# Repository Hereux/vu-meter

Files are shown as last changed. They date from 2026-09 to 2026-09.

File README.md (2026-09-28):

# Bass-SPL-Meter (10-100 Hz)

Selbstbau-Messgerät für Schalldruckpegel im Subbassbereich — für Showcars und
Car-Audio-Anlagen. Zeigt kalibrierten Pegel in dB SPL und die dominante
Frequenz an, vergleichbar mit kommerziellen Geräten wie dem Basshead Garage
BHG-DB.

## Eckdaten

| | |
|---|---|
| Messbereich | ca. 95 … 178 dB SPL |
| Frequenzbereich | 10 … 100 Hz, im Menü auf 5 … 150 Hz umschaltbar |
| Frequenzauflösung | 0,6-1,2 Hz (FFT), f0 auf < 0,01 Hz interpoliert |
| Anzeige | 2,8" TFT: Pegel, Peak-Hold, dominante Frequenz, Spektrum |
| Messwandler | Absolut-Drucksensor BMP581 (kein Mikrofon) |
| Rechner | ESP32 |
| Versorgung | 9-18 V Bordnetz |
| Materialkosten | 55 EUR (AliExpress) bis 95 EUR (deutsche Shops) |

## Grundidee

Ein Mikrofon scheidet aus: bezahlbare Kapseln clippen ab ~130 dB und sind unter
20 Hz taub. Ein barometrischer Absolut-Drucksensor misst dagegen bis ~178 dB,
reicht bis 0 Hz hinunter und liefert den Messwert **direkt in Pascal** — die
Kalibrierung ist damit ab Werk gegeben, statt von einer unbekannten
Mikrofonempfindlichkeit abzuhängen.

## Dokumentation

| Datei | Inhalt |
|---|---|
| [docs/01-messprinzip.md](docs/01-messprinzip.md) | Warum Drucksensor statt Mikrofon, Physik, Sensorauswahl, Aliasing |
| [docs/02-hardware.md](docs/02-hardware.md) | Stückliste mit Preisen, Blockschaltbild, Pinbelegung, Bordnetzschutz |
| [docs/03-firmware.md](docs/03-firmware.md) | Signalkette, FFT-Parameter, Betriebsmodi, Codestruktur |
| [docs/04-gehaeuse.md](docs/04-gehaeuse.md) | 3D-Druck, Material, Druckport, Entkopplung, Montage |
| [docs/05-kalibrierung.md](docs/05-kalibrierung.md) | Gain-Prüfung per Wassersäule, Frequenzgang, Grenzen des Geräts |
| [docs/06-phase1-ergebnisse.md](docs/06-phase1-ergebnisse.md) | Messergebnisse des DSP-Modells und die Befunde daraus |
| [docs/07-warum-cpp.md](docs/07-warum-cpp.md) | Warum die Gerätesoftware C++ ist und Python die Referenz bleibt |
| [docs/08-einkaufsliste.md](docs/08-einkaufsliste.md) | Bezugsquellen, Artikelnummern, zwei Bestellwege |
| [firmware/README.md](firmware/README.md) | Aufbau der Firmware, Testen ohne Hardware |
| [case/README.md](case/README.md) | Gehäusemodell, Messliste, Druckeinstellungen |
| **[TASKS.md](TASKS.md)** | **Abarbeitungsliste in 9 Phasen mit Abnahmekriterien** |

## Werkzeuge

```bash
python3 tools/spl_calc.py          # Auslegung: Pegel/Druck, Sensorreserve, FFT-Parameter
python3 tools/dsp_model.py         # Referenzmodell der Messkette, Kennwerttabellen
python3 tools/test_dsp_model.py    # 99 Abnahmetests, Exitcode 0 = bestanden
python3 tools/export_reference.py  # Sollwerte fuer die C++-Portierung erzeugen
```

Alles reine Standardbibliothek — kein numpy, kein scipy, keine Installation.

```bash
make -C firmware test   # 142 Abnahmetests der C++-Portierung, nur g++ noetig
make -C firmware bench  # Durchsatzmessung
```

## Status

**Phase 1 abgeschlossen, Phase 3 vorgezogen, soweit ohne Hardware möglich.**

- DSP-Referenzmodell in Python: Pegelfehler ±0,03 dB, Frequenzfehler ±0,01 Hz
  über das gesamte Messband, 99 Tests → [docs/06-phase1-ergebnisse.md](docs/06-phase1-ergebnisse.md)
- C++-Portierung für den ESP32: 151 Tests gegen die Referenzwerte des Modells,
  läuft ohne Board → [firmware/README.md](firmware/README.md)
- Parametrisches Gehäusemodell mit Passungslehre und 1:1-Papiervorlage
  → [case/README.md](case/README.md)

Als Nächstes: **Phase 0 (Bestellung)** — sie blockiert alles Weitere. Danach
Phase 2 (Sensor-Bringup) aus [TASKS.md](TASKS.md).

## Hinweis

Kein geeichtes Messgerät. Keine Zertifizierung nach IEC 61672, nicht für
offizielle Wettbewerbsergebnisse geeignet. Details in
[docs/05-kalibrierung.md](docs/05-kalibrierung.md), Abschnitt E.

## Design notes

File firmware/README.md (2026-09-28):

# Firmware

Die Messkette ist in zwei Schichten geteilt:

| Schicht | Dateien | Hardware nötig? | Status |
|---|---|---|---|
| DSP-Kern | `src/dsp.*`, `src/spectrum.*`, `src/meter.*` | nein | **fertig, 142 Tests grün** |
| Zielsystem | `src/main.cpp` | ja | läuft, auch ohne Sensor — siehe Demobetrieb |

Der DSP-Kern ist frei von Arduino- und ESP-IDF-Abhängigkeiten. Genau deshalb
läuft derselbe Code im PC-Test, der ihn gegen die Referenzwerte aus dem
Python-Modell prüft.

## Testen ohne Hardware

```bash
make -C firmware test     # 142 Abnahmetests gegen tools/dsp_model.py
make -C firmware bench    # Durchsatzmessung
```

Nur `g++` nötig. Mit PlatformIO alternativ `pio test -e native`.

## Aufs Board bringen

```bash
pio run -e esp32 -t upload --upload-port COM13   # Windows
pio run -e esp32 -t upload --upload-port /dev/ttyUSB0
pio device monitor -b 115200 -p COM13            # Ausgabe mitlesen
```

Wer keine Toolchain einrichten will: der CI-Lauf legt die Binärdateien als
Artefakt `firmware-esp32` ab (Actions-Tab → Lauf öffnen → Artifacts). Flashen
dann mit `esptool`:

```
esptool.py --port COM13 --chip esp32 write_flash \
  0x1000 bootloader.bin 0x8000 partitions.bin 0x10000 firmware.bin
```

Vorher die TFT-Flags in `platformio.ini` und die Pinbelegung in
`include/config.h` gegen die eigene Boardrevision prüfen — von den CYD-Boards
gibt es mehrere Varianten.

### Hintergrundbeleuchtung

GPIO 21, aktiv HIGH, per PWM geregelt (`cfg::kBacklightDefault`, Vorgabe 80 %).
Der aktuelle Wert steht in der Statuszeile.

**GPIO 21 darf nicht für I²C verwendet werden**, obwohl 21/22 die
Arduino-Standardpins sind: `Wire.begin()` konfiguriert den Pin um und schaltet
die Beleuchtung aus. Das Display zeigt dann ein korrektes, aber dunkles Bild.
Zwei `static_assert` in `include/config.h` verhindern das jetzt zur
Übersetzungszeit — I²C liegt auf 27/22.

## Demobetrieb ohne Sensor

Findet die Firmware beim Start keinen BMP581, schaltet sie automatisch in den
Demobetrieb: ein synthetischer Sinus-Sweep von 20 auf 80 Hz bei 150 dB läuft
durch **dieselbe Messkette** wie später der echte Schall.

Damit lässt sich schon vor dem Sensor prüfen:

- Display, Rotation und Farben stimmen
- die Rechenkette läuft auf echter Hardware in Echtzeit
- die Anzeige zeigt plausible Werte: **150,0 dB** konstant, die Frequenz
  wandert in 12 s von 20 auf 80 Hz und springt dann zurück

Weicht der angezeigte Pegel von 150 dB ab oder hakt die Frequenz, stimmt etwas
in der Kette oder am Timing nicht — das ist der eigentliche Zweck.

Die Sensorerkennung liest nur die Chip-ID (0x50) auf 0x47 bzw. 0x46. Dafür
braucht es keine Herstellerbibliothek; der richtige Treiber kommt in Phase 2.

Bleibt das Display dunkel: die serielle Ausgabe alle 5 s zeigt dieselben Werte.
Kommt dort etwas an, läuft die Firmware und nur die Display-Konfiguration
stimmt nicht.

## Referenzwerte neu erzeugen

Nach jeder Änderung am Python-Modell:

```bash
python3 tools/test_dsp_model.py     # erst das Modell absichern
python3 tools/export_reference.py   # dann die Sollwerte neu schreiben
make -C firmware test               # dann die Portierung dagegen prüfen
```

Diese Reihenfolge ist wichtig: die Referenzwerte sind nur so gut wie das
Modell, aus dem sie stammen.

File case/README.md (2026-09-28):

# Gehäuse und Druckteile

Parametrisches OpenSCAD-Modell. Alle Maße stehen in `params.scad` — das ist
die einzige Datei, die du anfassen musst.

## ⚠️ Zuerst lesen: die Maße sind nicht verifiziert

Die mit `MESSEN` markierten Werte in `params.scad` sind **plausible
Startwerte, keine gemessenen**. Die im Netz auffindbaren Angaben zum
ESP32-2432S028R widersprechen sich (78 × 42 mm gegen 102 × 68 mm), und die dort
genannte Displayfläche passt rechnerisch nicht zu 2,8" Diagonale: bei 320 × 240
im Format 4:3 ergeben sich 56,9 × 42,7 mm aktive Fläche.

Ich konnte das nicht auflösen — die Shop- und Datenblattseiten sind aus meiner
Arbeitsumgebung nicht erreichbar. Also: **nachmessen, bevor du druckst.**

## Ablauf, der Fehldrucke vermeidet

```
1.  Papiervorlage      make drawing    ->  img/template.svg
    Ausdrucken bei 100 % (Skalierung im Druckdialog AUS), Platine drauflegen.
    Kostet ein Blatt Papier.

2.  Maße eintragen     params.scad
    Messschieber an die Platine, Werte ersetzen.

3.  Passungslehre      make fit        ->  stl/fit_test.stl
    ca. 15 min Druckzeit. Prüft Spiel, Gewindeeinsatz, USB-Ausschnitt,
    Wandstärke und Auflagehöhe -- an echter Geometrie, nicht an einer Kopie:
    fit_test.scad schneidet ein 25 mm langes Stück aus der echten Rückschale.

4.  Erst dann          make            ->  alle STLs
    Das Gehäuse braucht etwa 6 Stunden. Die 15 Minuten vorher sind gut angelegt.
```

## Messliste

Mit dem Messschieber an die Platine, Werte in `params.scad` eintragen:

| Parameter | Was messen |
|---|---|
| `pcb_l`, `pcb_w`, `pcb_t` | Platinenumriss und -dicke |
| `pcb_top_h` | höchstes Bauteil **über** der Platine (meist der Displayrahmen) |
| `pcb_bot_h` | höchstes Bauteil **unter** der Platine |
| `win_l`, `win_w` | sichtbare Displayfläche, plus ~1 mm Reserve |
| `win_off_l`, `win_off_w` | Versatz des Displays gegenüber der Platinenmitte |
| `usb_w`, `usb_h`, `usb_off` | USB-Buchse: Breite, Höhe, Versatz aus der Mitte |
| `sd_w`, `sd_h`, `sd_off` | microSD-Schlitz |
| `insert_d`, `insert_h` | die tatsächlich gelieferten Gewindeeinsätze |
| `sensor_pcb_l/w` | Breakout-Platine des BMP581 |

## Teile

| Datei | Was | Druckzeit |
|---|---|---|
| `stl/fit_test.stl` | Passungslehre — **das zuerst** | ~15 min |
| `stl/back.stl` | Rückschale mit Sensorkammer | ~4 h |
| `stl/bezel.stl` | Frontblende | ~2 h |
| `stl/cal_cup.stl` + `cal_lid.stl` | Kalibrierkammer, siehe unten | ~1,5 h |

## Die zwei Kammern nicht verwechseln

**Sensorkammer am Gerät** (`case.scad`, `sensor_pod`): auf allen vier Seiten
**offen**. Genau so soll es sein — ein dichtes Volumen wirkt als Hochpass und
dämpft die tiefen Frequenzen weg, um die es hier geht. Über die Öffnungen kommt
offenporiger Schaumstoff gegen Staub und direkten Luftzug; der ist bei diesen
Frequenzen akustisch transparent.

**Kalibrierkammer** (`sensor_chamber.scad`): **dicht**. Nur in einem
geschlossenen Volumen lässt sich dem Sensor ein bekannter Überdruck vorsetzen.
Details in [../docs/05-kalibrierung.md](../docs/05-kalibrierung.md).

Ein Schraubglas tut es übrigens auch — die gedruckte Kammer hat nur schon die
Schlauchtülle dran.

## Druckeinstellungen

| | |
|---|---|
| Material | **ASA oder PETG. Kein PLA** — im Fahrzeug bis 80 °C, PLA verformt sich ab 55 °C |
| Schichthöhe | 0,2 mm |
| Perimeter | 4 — das Gehäuse muss steif sein, sonst schwingt es bei 150 dB selbst mit |
| Infill | 25 % |
| Stützen | keine, außer an der Schlauchtülle der Kalibrierkammer |
| Orientierung | Rückschale mit dem Boden aufs Bett, Sensorkammer nach oben |

Gewindeeinsätze mit dem Lötkolben bei ~230 °C einschmelzen, senkrecht und ohne
Druck. Direkt gedruckte Gewinde reißen bei Vibration aus.

## Nach dem Zusammenbau

Die Sensorplatine auf 2 mm Moosgummi setzen und nur leicht andrücken. Bei
150 dB wird das Gehäuse selbst zur schwingenden Masse; ein starr verschraubter
Sensor misst diese Beschleunigung als Scheindruck mit.

**Frequenzgang nach dem Einbau erneut messen** (Phase 6.5). Das Gehäuse ist der
wahrscheinlichste Fehlerort im ganzen Projekt.

## Eine Notiz zum Modell selbst

Beim Erstellen sind sechs Fehler aufgefallen, alle erst beim Ansehen der
gerenderten Bilder, nicht beim Kompilieren:

- Der Innenraum war nur um die Platine herum ausgehöhlt — die Stirnseiten
  blieben massiv stehen, der USB-Ausschnitt wäre ein 8 mm tiefer Tunnel
  gewesen, in den kein Stecker passt.
- Ein `rotate()` vertauschte Breite und Wanddurchbruch des microSD-Schlitzes.
- Lüftungsschlitze schnitten in den microSD-Ausschnitt.
- Die Sensorkammer dünnte den Wannenboden auf 1,2 mm aus.
- Die Zugentlastungspfosten standen auf massivem Material außerhalb des
  Innenraums und waren damit wirkungslos.
- Ein Zugentlastungspfosten lag exakt tangential an einer Auflageleiste. Eine
  Berührung ohne Durchdringung — daran scheitert CGAL, und das STL wurde
  nicht-mannigfaltig.

Dass so etwas beim reinen Kompilieren durchgeht, ist der Grund für die
Papiervorlage und die Passungslehre.

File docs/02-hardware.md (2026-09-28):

# 2. Hardware und Stückliste

## Architektur

```
 12 V Bordnetz
   |  Sicherung 1 A + Verpolschutz + TVS (SMBJ24A)
   v
 DC/DC 12 V -> 5 V (MP1584 / LM2596)
   |
   v
 ESP32-2432S028R  ("Cheap Yellow Display")
   +-- 2.8" TFT 320x240 ILI9341 (SPI, onboard)
   +-- microSD (SPI, onboard)  -> Logging
   +-- I2C (GPIO 27 SDA / 22 SCL)              --> BMP581
   +-- Taster (GPIO 35 o. Touch)               --> Mode / Peak-Reset
   +-- WLAN (optional)                          --> Web-UI / OTA
```

## Stückliste

| # | Teil | Zweck | Preis (EUR) | Quelle |
|---|---|---|---|---|
| 1 | ESP32-2432S028R, 2.8" TFT + microSD + Touch | MCU + Display + Logging in einem | 12-16 | AliExpress, Amazon |
| 2 | BMP581 **Breakout-Platine** (SparkFun Qwiic / DFRobot / generisch) | Messwandler | 12-29 | AliExpress ~12-15, Eckstein/BerryBase ~27-29. **Kein nackter LGA-10-Chip** |
| 3 | DC/DC 12 V -> 5 V, **fester** Ausgang, Eingang bis >= 40 V | Bordnetzversorgung | 3-7 | AliExpress ~3, oder RECOM R-78B50-10 (Reichelt Art. 159150) ~7 |
| 4 | TVS SMBJ24A, Schottky SS34, Sicherungshalter + 1 A Flachsicherung | Load-Dump-/Verpolschutz | 3-5 | Reichelt |
| 5 | Elkos 470 µF/35 V + 100 µF/10 V, Ferritperle | Siebung, Störunterdrückung | 2 | Reichelt |
| 6 | Kabel 2×0,75 mm², JST-XH-Steckverbinder, Schrumpfschlauch | Verkabelung | 4 | — |
| 7 | Filament ASA oder PETG, ~80 g | Gehäuse (hitzefest im Auto) | 2-3 | — |
| 8 | Gewindeeinsätze M3 (8×), Schrauben M3×8 | Gehäuseverschraubung | 3 | — |
| 9 | Saugnapfhalterung 30 mm (2×) oder GoPro-Mount | Befestigung Scheibe/Armaturenbrett | 4-7 | — |
| 10 | Taster 12 mm wasserdicht (optional, sonst Touch) | Peak-Reset | 2 | — |
| | **Summe** | | **55-95** | |

Optional im Budgetrahmen:

| Teil | Zweck | Preis |
|---|---|---|
| Zweiter Sensor BMP390 | Plausibilitätsprüfung / Redundanz | 8-12 |
| Kalibrier-Set: Schlauch 6 mm, 60 ml Spritze, Lineal | statische Gain-Prüfung (siehe Doc 05) | 5 |
| Bluetooth-/WLAN-Logging (nur Software) | Auswertung am Handy | 0 |

**Gesamt realistisch 55 EUR (AliExpress-Weg) bis 95 EUR (deutscher Weg)**
inkl. Kalibrierhilfsmittel — beides im Budgetrahmen.

Konkrete Bezugsquellen mit Artikelnummern: [08-einkaufsliste.md](08-einkaufsliste.md).

## Warum das ESP32-2432S028R-Board

Es ist die mit Abstand kosteneffektivste Option: ESP32-WROOM-32, 2,8" TFT,
Touch, microSD, USB-Seriell, Spannungsregler und LDR schon verbaut, für den
Preis eines nackten DevKits. Die klassische ESP32 leistet eine 512-Punkt-FFT bei
600 Hz Abtastrate mit <2 % CPU-Last — mehr als ausreichend.

Falls ein größerer Rechenpuffer oder besseres Sonnenlichtverhalten gewünscht
ist:
- **ESP32-S3 DevKitC-1 N16R8** (~14 EUR) + separates Display.
- **1,3" SH1106 OLED** (~7 EUR) statt TFT: bessere Ablesbarkeit bei Sonne, aber
  128×64 Pixel — Spektrumanzeige nur grob. Entspricht dem kommerziellen BHG-DB.

## Pinbelegung (ESP32-2432S028R)

| Signal | GPIO | Hinweis |
|---|---|---|
| I²C SDA | 27 | **nicht 21** — dort liegt die Beleuchtung, siehe unten |
| I²C SCL | 22 | |
| Hintergrundbeleuchtung | 21 | aktiv HIGH, per PWM geregelt |
| BMP581 VDD | 3V3 | max. 3,6 V, nicht an 5 V |
| BMP581 INT | 35 | optional, Data-Ready-Interrupt (nur Eingang!) |
| Taster | 0 / Touch | Peak-Reset |

> Pinbelegung vor dem Löten gegen die konkrete Boardrevision prüfen — bei den
> CYD-Boards gibt es mehrere Varianten. Frei sind üblicherweise GPIO 22, 27 und
> 35 (nur Eingang); TFT, Touch, SD, RGB-LED, LDR und Lautsprecher belegen den
> Rest.

**GPIO 21 ist die Hintergrundbeleuchtung, nicht frei.** Das ist die
Stolperfalle des Boards: 21/22 sind die Arduino-Standardpins für I²C, und wer
sie benutzt, bekommt ein funktionierendes Display mit dunkler Beleuchtung —
`Wire.begin()` konfiguriert GPIO 21 um und schaltet das Licht aus. Genau das
ist hier einmal passiert. `firmware/include/config.h` fängt es seitdem zur
Übersetzungszeit mit einem `static_assert` ab.

I²C mit 400 kHz. Bei 32-Byte-FIFO-Burst alle ~50 ms ist die Buslast minimal.
Kabel zum Sensor kurz halten (<30 cm) oder auf SPI wechseln.

## Elektrische Auslegung Bordnetz

Ein Showcar-Bordnetz ist rau: 9-18 V im Normalbetrieb, Load-Dump-Spitzen,
Ripple von der Endstufe.

1. Flachsicherung 1 A direkt an der Einspeisung.
2. Verpolschutz: Schottky SS34 in Reihe (0,4 V Verlust, unkritisch).
3. TVS SMBJ24A parallel gegen Spitzen.
4. 470 µF/35 V vor dem Wandler, Ferritperle + 100 µF nach dem Wandler.
5. Masse **sternförmig** an einem Punkt, nicht an der Endstufenmasse — sonst
   koppelt der Ripple als Störsignal ein.

Der Drucksensor ist immun gegen elektromagnetische Einstreuung der Endstufe
(digitaler Bus, kein analoges Mikrofonsignal) — ein weiterer Vorteil gegenüber
Mikrofonlösungen.

## Mechanische Anforderungen an den Sensor

- Der Sensorport muss **offen zum Fahrzeuginnenraum** liegen, kein geschlossenes
  Gehäusevolumen. Ein abgedichtetes Gehäuse wirkt als Hochpass und verfälscht
  gerade unter 20 Hz massiv.
- Gleichzeitig Schutz vor direktem Luftzug und Staub: Port mit Schaumstoff
  (offenporig, ~5 mm) abdecken. Der ist bei diesen Frequenzen akustisch
  transparent.
- Sensorplatine mechanisch entkoppeln (Moosgummi), sonst misst man
  Gehäuseresonanzen mit.

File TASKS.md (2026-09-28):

# Abarbeitungsliste

Reihenfolge ist bewusst so gewählt, dass alles, was ohne Hardware prüfbar ist,
vor der ersten Bestellung geklärt wird. Jede Phase hat ein Abnahmekriterium —
erst wenn das erfüllt ist, geht es weiter.

---

## Phase 0 — Entscheidungen und Bestellung  (~1 Tag, 55-95 EUR)

- [ ] 0.1 Sensor festlegen: BMP581 (Standard) oder BMP390 (Fallback). Verfügbarkeit und Preis prüfen.
- [ ] 0.2 Display festlegen: ESP32-2432S028R mit 2,8" TFT (Standard) oder 1,3" OLED (bessere Sonnenlesbarkeit, kleinere Grafik).
- [ ] 0.3 Bestellung auslösen — **Einkaufsliste mit Bezugsquellen: [docs/08-einkaufsliste.md](docs/08-einkaufsliste.md)**. Lieferzeit AliExpress 2-4 Wochen einplanen.
- [ ] 0.4 Zielspezifikation schriftlich fixieren: Messbereich 95-178 dB, Band 10-100 Hz, Anzeige RMS + Peak + f0.

**Abnahme:** Bestellung raus, Spezifikation steht.

---

## Phase 1 — DSP am PC verifizieren  ✅ **abgeschlossen**

- [x] 1.1 `tools/spl_calc.py` durchgerechnet, gegen `docs/01-messprinzip.md` gegengeprüft.
- [x] 1.2 Referenzmodell der kompletten Kette gebaut (`tools/dsp_model.py`): DC-Blocker, umschaltbares Bandfilter, Hann-FFT, Peak-Interpolation, RMS/Peak-Detektoren. Ohne numpy/scipy, sample-by-sample — direkt nach C++ portierbar.
- [x] 1.3 Mit synthetischen Signalen getestet: Einzeltöne 10-100 Hz, Mehrton, Luftdruckdrift, Offsetvariation, float32-Quantisierung, Bandumschaltung.
- [x] 1.4 Geprüft: **Tonpfad ±0,03 dB und ±0,01 Hz** über das ganze Band, Linearität 110-178 dB besser 0,1 dB, Bandfilter schwingt in 0,019 s ein. Alle Vorgaben übertroffen.
- [x] 1.5 `tools/export_reference.py` erzeugt `firmware/test/reference_vectors.h` als Sollwertsatz für die C++-Portierung. **Keine** feste Koeffiziententabelle für die Firmware — siehe Befund 3.

**Abnahme erfüllt:** 99 von 99 Tests bestanden (`python3 tools/test_dsp_model.py`). Ergebnisse und Befunde in [docs/06-phase1-ergebnisse.md](docs/06-phase1-ergebnisse.md).

Drei Befunde, die in die Firmware einfließen:
1. Die FFT gehört **vor** das Bandfilter, sonst erbt die Frequenzanzeige die Filterflanke (3 dB Fehler an den Bandgrenzen). Peak-Suche zusätzlich ein Bin über die Grenzen hinaus.
2. Peak-Hold braucht eine **Einschwingsperre von 150 ms**, sonst landet der Überschwinger des Bandfilters als Spitzenpegel im Display (+4,10 statt +3,01 dB über RMS).
3. Biquad-Koeffizienten **zur Laufzeit** aus der gemessenen Abtastrate berechnen, nicht als Tabelle hinterlegen — der RC-Oszillator des Sensors weicht bis ±5 % ab.

---

## Phase 2 — Sensor-Bringup  (~1 Tag, nach Lieferung)

- [x] 2.0 CI baut die ESP32-Firmware (`.github/workflows/ci.yml`) und legt die Binärdateien als Artefakt ab. Bis dahin war `main.cpp` nie übersetzt worden — meine Arbeitsumgebung sperrt die PlatformIO-Registry. **Erster Lauf grün**, alle fünf Jobs: RAM 15,0 %, Flash 25,4 %, Bauzeit 48 s.
- [x] 2.0a Demobetrieb ohne Sensor: synthetischer Sweep durch die echte Messkette, Anzeige auf dem TFT. Prüfbar mit dem Board allein.
- [x] 2.1 Firmware geflasht, Anzeige läuft. **Befund:** Bild korrekt, Beleuchtung aus — I²C lag auf GPIO 21, dem Backlight-Pin. Behoben: I²C auf 27/22, Beleuchtung per PWM regelbar, zwei `static_assert` gegen eine Wiederholung.
- [ ] 2.1a Nachprüfen: Beleuchtung an, Helligkeit in der Statuszeile, Pegel weiterhin 150,0 dB und Sweep 20 → 80 Hz.
- [ ] 2.2 BMP581 per I²C anbinden, Chip-ID lesen, Absolutdruck plausibel (800-1100 hPa)?
- [ ] 2.3 Continuous Mode, OSR 1x, IIR aus, FIFO aktivieren.
- [ ] 2.4 FIFO-Burst-Read alle 40 ms, Overrun-Flag auswerten.
- [ ] 2.5 **fs-Kalibrierung**: über 30 s Samples zählen, reale Abtastrate bestimmen und in NVS speichern. Gerüst in `src/main.cpp`, TODOs markiert. Bei Overrun muss die Zählung neu starten, sonst kommt die Rate zu niedrig heraus.
- [ ] 2.6 Rohdaten über USB-Seriell streamen und am PC mit `tools/verify_log.py` plotten.

**Abnahme:** Lückenloser Datenstrom mit bekannter, stabiler Abtastrate (Schwankung < 0,5 %), keine FIFO-Overruns über 10 Minuten.

---

## Phase 3 — Messkette auf dem ESP32  (~2 Tage)

Der hardwareunabhängige Teil ist **vorgezogen und fertig** — er brauchte kein Board.

- [x] 3.1 Python-Modell nach C++ portiert (`firmware/src/dsp.*`, `spectrum.*`, `meter.*`). Frei von Arduino-Abhängigkeiten, damit derselbe Code im PC-Test läuft. FFT vor dem Bandfilter.
- [x] 3.2 Abnahmetest gegen `reference_vectors.h`: **142 Tests grün**, goldener Vektor auf 0,007 Pa reproduziert. `make -C firmware test`, nur g++ nötig.
- [x] 3.3 ~~ESP-DSP-FFT~~ **nicht nötig.** Eigene Radix-2-FFT mit vorberechneten Drehfaktoren. Bei N=1024 und Hop N/4 läuft sie 2,4-mal je Sekunde; gemessener Durchsatz 0,14 µs pro Sample, das sind unter 1 % Rechenzeit auf dem ESP32. Spart eine Abhängigkeit und macht den Code nativ testbar.
- [x] 3.4 Sinc-Korrektur (pro Bin im Spektralpfad, über f0 im Detektorpfad) und Peak-Interpolation, Peak-Suche ein Bin über die Bandgrenzen hinaus.
- [x] 3.4a Biquad-Auslegung zur Laufzeit aus der gemessenen Abtastrate.
- [x] 3.4b Einschwingsperre (150 ms) für Peak- und Max-Hold nach Start, Reset und Bandwechsel.
- [x] 3.4c **Neuer Befund:** obere Bandgrenze ≤ 0,4 × Abtastrate erzwungen. Genau auf Nyquist entartet der Tiefpass; ein unzulässiges Band wird jetzt abgelehnt statt still kaputt gebaut. Folge: BMP390 mit 200 Hz schafft höchstens 80 Hz obere Grenze.
- [ ] 3.5 Erster Realtest: Sub mit Sinus 30 Hz ansteuern, Pegel schrittweise erhöhen, Linearität prüfen (10 dB mehr Anregung → 10 dB mehr Anzeige). **Braucht Hardware.**
- [ ] 3.6 CPU-Last und Task-Timing auf dem Board bestätigen; Sensor-Task auf Kern 0 mit hoher Priorität, Anzeige auf Kern 1. Gerüst steht in `src/main.cpp`. **Braucht Hardware.**

**Abnahme (PC-Teil) erfüllt:** 142 von 142 Tests bestanden. Begründung der Sprachwahl und Messwerte in [docs/07-warum-cpp.md](docs/07-warum-cpp.md).
**Abnahme (Board-Teil) offen:** Angezeigter Pegel folgt linear der Anregung, f0 stimmt mit dem Generator auf < 0,2 Hz überein.

---

## Phase 4 — Bedienoberfläche  (~2 Tage)

- [ ] 4.1 Screen LIVE: große dB-Zahl, f0, Balkenspektrum 10-100 Hz.
- [ ] 4.2 Screen PEAK/BURP: max. RMS groß, True-Peak als Nebenwert, f0 beim Maximum, Reset per langem Tastendruck.
- [ ] 4.2a Bandumschaltung 10-100 / 5-150 Hz im Menü; Wechsel muss die Haltewerte zurücksetzen.
- [ ] 4.3 Screen RTA: 1/6-Oktav-Balken mit Max-Hold, N=1024.
- [ ] 4.4 Statuszeile: `dB SPL (Z, 10-100 Hz)`, fs, Temperatur, OVER-/Overrun-Warnung.
- [ ] 4.4a Debug-/Kalibrierscreen: zeigt `rawPressurePa` (Absolutdruck vor dem DC-Blocker) und die Sensortemperatur. Ohne den ist der Wassersäulen-Test aus Phase 5.1 nicht durchführbar.
- [ ] 4.5 Modusumschaltung per Taster/Touch, Einstellungen in NVS persistent.
- [ ] 4.6 Ablesbarkeit prüfen: aus 1,5 m Entfernung bei Tageslicht lesbar? Sonst Schriftgröße/Kontrast anpassen.

**Abnahme:** Alle Modi bedienbar, Anzeige auch bei Erschütterung stabil, Refresh ≥ 4 Hz.

---

## Phase 5 — Kalibrierung und Verifikation  (~1 Tag)

- [ ] 5.0 Sofort-Check vor allem anderen: Gerät 10 m höher tragen, Rohdruck muss um ~120 Pa fallen. Deckt grobe Skalierungsfehler in zwei Minuten auf.
- [ ] 5.1 Wassersäulen-Test (`docs/05-kalibrierung.md` A): dichte Sensorkammer bauen, Reihe über 10/20/50 cm, Hauptmesspunkt 50 cm. Abweichung < 1 %.
- [ ] 5.2 Rauschteppich im ruhigen Raum messen und dokumentieren.
- [ ] 5.3 Frequenzgang mit DIY-Pistonphon oder Zweitsensor-Vergleich (10-100 Hz, ±0,5 dB erwartet).
- [ ] 5.4 Clipping-Grenze nachrechnen und Warnschwelle in der Firmware setzen (175 dB).
- [ ] 5.5 `docs/kalibrierprotokoll.md` ausfüllen.

**Abnahme:** Gain auf ±1 % bestätigt, Frequenzgang dokumentiert, Grenzen bekannt.

---

## Phase 6 — Gehäuse  (~2-3 Tage inkl. Druckzeit) — Modell fertig, Rest braucht Hardware

- [x] 6.1 OpenSCAD-Modell erstellt (`case/`): Rückschale mit belüfteter Sensorkammer, Frontblende, Kalibrierkammer, Passungslehre, 1:1-Papiervorlage. Alle STLs als manifold geprüft.
- [ ] 6.1a **Platine vermessen** und die `MESSEN`-Werte in `case/params.scad` eintragen. Die Startwerte sind geraten — die Netzangaben zum Board widersprechen sich.
- [ ] 6.2 Papiervorlage bei 100 % ausdrucken, Platine drauflegen. Dann Passungslehre drucken (`make -C case fit`, ~15 min), erst danach das Gehäuse (~6 h).
- [ ] 6.3 Vollständiger Druck in ASA/PETG, Gewindeeinsätze einschmelzen.
- [ ] 6.4 Montage, Sensor auf Moosgummi entkoppeln, Schaumstoff über den Port.
- [ ] 6.5 **Frequenzgang nach dem Einbau erneut messen** (Phase 5.3 wiederholen) — das Gehäuse ist der wahrscheinlichste Fehlerort.
- [ ] 6.6 STL-Export nach `case/stl/`.

**Abnahme:** Frequenzgang im Gehäuse weicht < 1 dB vom Freiluftwert ab. Sonst: Port vergrößern, Kammervolumen verkleinern.

---

## Phase 7 — Fahrzeugeinbau und Feldtest  (~1 Tag)

- [ ] 7.1 Spannungsversorgung aufbauen: Sicherung, Verpolschutz, TVS, DC/DC. Ohne angeschlossenes Board erst die 5 V messen.
- [ ] 7.2 Sternmasse anlegen, nicht an der Endstufenmasse.
- [ ] 7.3 Einbau, Messposition festlegen und dokumentieren.
- [ ] 7.4 Störtest: Anlage auf Vollgas, dabei prüfen, ob Messwerte plausibel bleiben und das Board nicht resettet.
- [ ] 7.5 Sweep 10-100 Hz fahren, Kurve loggen, mit der bekannten Abstimmung des Gehäuses vergleichen (Impedanzminimum/Tuningfrequenz sollte sich als Pegelmaximum zeigen).
- [ ] 7.6 Wenn möglich: Gegenmessung mit einem kommerziellen Gerät.

**Abnahme:** Reproduzierbare Messwerte (Wiederholung derselben Messung < 1 dB Streuung), keine elektrischen Störungen.

---

## Phase 8 — Optional / Ausbau

- [ ] 8.1 CSV-Logging auf microSD, Auswertung mit `tools/verify_log.py`.
- [ ] 8.2 WLAN-AP mit Web-Oberfläche: Live-Spektrum und Download der Logs am Handy.
- [ ] 8.3 OTA-Update.
- [ ] 8.4 Zweiter Sensor (BMP390) als Dauer-Plausibilitätsprüfung.
- [ ] 8.5 Auto-Dimming des Displays über den onboard LDR.
- [ ] 8.6 Gesamtdoku und Bauanleitung als Release veröffentlichen.

---

## Zeit- und Kostenrahmen

| | |
|---|---|
| Aktive Arbeitszeit | ca. 10-13 Tage, gut in Abendetappen machbar (Phase 1 erledigt) |
| Wartezeit Lieferung | 2-4 Wochen (parallel zu Phase 1) |
| Materialkosten | 55 EUR (AliExpress) bis 95 EUR (deutsche Shops) |

## Größte Risiken

| Risiko | Gegenmaßnahme |
|---|---|
| Gehäuse dämpft tiefe Frequenzen | Offener Port, kleine Kammer, Messung in Phase 6.5 |
| Falsche Abtastrate → falsche Frequenzanzeige | fs-Kalibrierung in Phase 2.5, Pflichtschritt |
| Bordnetzstörungen / Resets | Schutzbeschaltung Phase 7.1, Sternmasse |
| Sensor am Anschlag bei Extrempegeln | Clipping-Erkennung Phase 5.4, Grenze bei 178 dB |
| Vibration verfälscht Messung | Sensorentkopplung Phase 6.4 |

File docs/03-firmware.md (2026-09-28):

# 3. Firmware

Toolchain: **PlatformIO + Arduino-Framework für ESP32**. Bibliotheken:
`SparkFun_BMP581_Arduino_Library`, `TFT_eSPI`, `ESP-DSP` (FFT), `SD`.

> Die komplette Kette ist in Phase 1 als Referenzmodell gebaut und abgesichert:
> `tools/dsp_model.py`, 99 Abnahmetests in `tools/test_dsp_model.py`.
> Messergebnisse und drei daraus folgende Konstruktionsentscheidungen stehen in
> [06-phase1-ergebnisse.md](06-phase1-ergebnisse.md).

## Signalkette

```
BMP581 FIFO (fs ~500-622 Hz, OSR 1x, IIR aus)
   |  Burst-Read 32 Werte alle ~40 ms
   v
Ringpuffer  [float Pa]
   |
   +-- DC-Blocker: Hochpass 1. Ordnung @ 0,5 Hz   (Luftdruck, Wetterdrift)
   |
   +---------------------------+
   |                           |
   v                           v
Bandfilter                  Hann-FFT (N=512/1024, Hop N/4)
Butterworth 4. Ord.         Peak-Bin + parabolische Interpolation
HP + LP, umschaltbar        + Sinc-Korrektur pro Bin
10-100 Hz / 5-150 Hz           |
   |                           +-> f0 (dominante Frequenz)
   +-> RMS Fast (125 ms)       +-> Tonpegel (Hauptkeule, Peak +/- 2 Bins)
   +-> RMS Slow (1 s)          +-> Bandpegel (Parseval, rechteckige Grenzen)
   +-> True-Peak               +-> Spektrum fuer die RTA-Anzeige
   +-> Max-Hold
   |
   +-- Sinc-Korrektur ueber f0
```

**Die FFT hängt bewusst vor dem Bandfilter.** Läge sie dahinter, erbte die
Frequenz- und Tonpegelanzeige die −3 dB der Filterflanke, und ein Ton genau auf
einer Bandgrenze würde 3 dB zu niedrig angezeigt. Die Bandgrenzen wirken im
Spektralpfad stattdessen rechteckig über die Bin-Auswahl. Die Peak-Suche läuft
dabei ein Bin über die Bandgrenzen hinaus, sonst läuft die Interpolation bei
einem Ton exakt auf der Grenze in ihre Begrenzung.

## Messbänder

Im Menü umschaltbar. Die Grenzen sind die −3-dB-Punkte des Bandfilters, wie bei
Messfiltern üblich.

| Band | Zweck |
|---|---|
| **10-100 Hz** | Vergleichbarkeit mit kommerziellen Bass-Metern |
| **5-150 Hz** | erfasst Infraschall unter 10 Hz und unteren Kickbass, liest je nach Musik 1-3 dB höher |

Das aktive Band steht immer in der Statuszeile. Ein Bandwechsel muss die
Haltewerte zurücksetzen (siehe Einschwingsperre).

## Koeffizienten zur Laufzeit berechnen

Keine festen Koeffiziententabellen im Code. Der Sensor taktet mit einem
internen RC-Oszillator, die reale Abtastrate weicht bis zu ±5 % vom Nennwert
ab — eine Tabelle für „622 Hz" wäre um genau diesen Fehler daneben, sowohl in
den Filtergrenzen als auch in der FFT-Frequenzachse. Die Firmware legt die acht
Biquads beim Start aus der gemessenen Abtastrate aus (zwei `sin`/`cos` pro
Sektion, vernachlässigbar).

## Einschwingsperre für die Haltewerte

Ein Butterworth-Bandfilter überschwingt beim Einschwingen um gut 1 dB. Ohne
Gegenmaßnahme landet dieser Überschwinger als vermeintlicher Spitzenpegel im
Peak-Hold — im Test **+4,10 dB statt +3,01 dB** über RMS. Nach Start,
Peak-Reset und Bandwechsel werden die Haltewerte deshalb 150 ms lang
eingefroren.

## Abtasttakt und Frequenzgenauigkeit

Der Sensor taktet sich selbst; die reale ODR weicht vom Nennwert ab (interner
RC-Oszillator, ±5 %). Das geht **1:1 in die Frequenzanzeige ein** — 5 % Fehler
bei 40 Hz sind 2 Hz, das ist beim Anlagentuning zu viel.

Lösung: beim Start einmalig kalibrieren.

```
fs_real = (Anzahl FIFO-Samples in T) / T,  T >= 10 s, gemessen mit esp_timer
```

Der Wert wird in NVS gespeichert und für Bandpass, Sinc-Korrektur und
FFT-Frequenzachse verwendet. Erneute Messung bei jedem Kaltstart (temperatur-
abhängig).

## FFT-Parameter

Basis fs = 500 Hz:

| N | Auflösung | Fensterlänge | Update | Einsatz |
|---|---|---|---|---|
| 256 | 1,95 Hz | 0,51 s | 0,13 s | Live-Balken, schnelle Reaktion |
| **512** | **0,98 Hz** | **1,02 s** | **0,26 s** | Standard |
| 1024 | 0,49 Hz | 2,05 s | 0,51 s | Tuning-Modus, feine f0-Bestimmung |

Mit parabolischer Interpolation über die Hann-Peakspitze ist f0 auch bei N=512
auf besser als 0,1 Hz bestimmbar, solange ein dominanter Ton anliegt.

## Betriebsmodi

| Modus | Anzeige | Detektor |
|---|---|---|
| **LIVE** | große dB-Zahl + f0 + Balkenspektrum | RMS Fast (125 ms) |
| **PEAK / BURP** | max. RMS groß, True-Peak als Nebenwert, f0 beim Maximum | beide, Reset per Taster |
| **RTA** | Spektrum 10-100 Hz, 1/6-Oktav-Balken, Max-Hold | N=1024 |
| **LOG** | läuft im Hintergrund | CSV auf microSD: `t,SPL_rms,SPL_peak,f0,band` @ 4 Hz |

Der PEAK-Modus zeigt **beide** Maxima: den größten RMS-Wert (125 ms) groß, den
True-Peak kleiner daneben. Bei einem Sinus liegen sie exakt 3,01 dB
auseinander; bei echter Musik zeigt der Abstand, wie impulshaltig das Signal
ist. Welcher Wert zitiert wird, entscheidet so der Anwender und nicht die
Firmware.

Umschaltung per Taster/Touch. Peak-Reset: langer Druck.

Anzeigewerte immer mit Bezug kennzeichnen: `dB SPL (Z, 10-100 Hz)`. Keine
A-Bewertung — die würde bei 30 Hz über 39 dB abziehen und ist für Bassmessung
sinnlos. Für Vergleichbarkeit mit Wettbewerbsmessungen zusätzlich den Peak-Wert
ausgeben, das ist dort der übliche Bezug.

## Zeitbudget (ESP32 @ 240 MHz)

| Task | Kern | Last |
|---|---|---|
| FIFO-Read + Filter | 0 | < 1 % |
| FFT 512 (ESP-DSP) | 0 | ~2 % bei 4 Hz Updaterate |
| Display-Refresh | 1 | 10-20 % |
| SD-Logging | 1 | < 5 % |

Reichlich Reserve. Sensor-Task mit hoher Priorität und eigenem Kern, damit der
Display-Refresh keine FIFO-Overruns verursacht (FIFO fasst nur 32 Werte ≈ 55 ms
bei 580 Hz — deshalb mindestens alle 40 ms auslesen).

## Speicherbelegung (gemessen)

Aus dem CI-Build mit Demobetrieb und TFT_eSPI, also inklusive Anzeige:

| | belegt | verfügbar | |
|---|---|---|---|
| RAM (statisch, zur Linkzeit) | 49 000 B | 327 680 B | 15,0 % |
| Flash | 332 437 B | 1 310 720 B | 25,4 % |

Der RAM-Wert ist die statische Belegung beim Linken; Task-Stacks und
FreeRTOS-Heap kommen zur Laufzeit dazu. Die FFT-Puffer im `Meter` sind darin
enthalten (Ringpuffer, Block und Betragsspektrum, zusammen rund 12 kB bei
N = 1024). Für Logging, WLAN und einen zweiten Sensor ist reichlich Platz.

Bauzeit im CI: 48 s.

## Absolutdruck-Ausgang

Der Report enthält neben den Pegelwerten den geglätteten **Absolutdruck vor dem
DC-Blocker** (`rawPressurePa`, Zeitkonstante 2 s) und ein Plausibilitätsflag.

Der Wert ist nicht für die normale Anzeige gedacht, sondern für die statische
Gain-Prüfung aus [05-kalibrierung.md](05-kalibrierung.md): dort wird der Sensor
in eine dichte Kammer gesetzt und mit einem bekannten Überdruck beaufschlagt.
Der DC-Blocker entfernt genau diese Größe — ohne separaten Ausgang wäre die
Kalibrierung also gar nicht durchführbar.

## Plausibilitätsprüfungen in der Firmware

- **FIFO-Overrun-Flag** auswerten → Messung als ungültig markieren, nicht still
  weiterrechnen.
- **Clipping-Erkennung**: Rohdruck außerhalb 350-1200 hPa → „OVER" anzeigen.
- **Temperatur** mitloggen; der BMP581 liefert sie ohnehin.
- **Sanity-Check beim Start**: `pressurePlausible` prüft 350-1200 hPa. Außerhalb
  stimmt etwas nicht — Sensor defekt, falsch verdrahtet, oder der Pegel sprengt
  den Messbereich.

## Struktur des Repos (geplant)

```
firmware/
  platformio.ini
  src/
    main.cpp            Task-Setup, Modus-Statemachine
    sensor_bmp581.cpp   Init, Continuous Mode, FIFO-Burst, fs-Kalibrierung
    dsp.cpp             Hochpass, Bandpass-Biquads, RMS/Peak, Sinc-Korrektur
    spectrum.cpp        Hann, FFT, Peak-Interpolation, Oktavbänder
    ui_tft.cpp          Screens, Balken, Zahlen
    logger.cpp          CSV auf SD
    config.h            Pins, fs-Default, Filtergrenzen, Kalibrieroffset
  test/
    test_dsp.cpp        Unit-Tests gegen synthetische Sinus-Signale
tools/
  spl_calc.py           Auslegungsrechner
  dsp_model.py          Referenzmodell der Messkette (Phase 1)
  test_dsp_model.py     99 Abnahmetests fuer das Modell
  export_reference.py   erzeugt reference_vectors.h
  verify_log.py         Auswertung der CSV-Logs am PC
```

## Verifikation der DSP-Kette ohne Hardware

Erledigt in Phase 1: das Python-Referenzmodell erreicht im Tonpfad über das
gesamte Band **±0,03 dB und ±0,01 Hz**, Linearität über 110 … 178 dB besser als
0,1 dB. Details in [06-phase1-ergebnisse.md](06-phase1-ergebnisse.md).

`tools/export_reference.py` erzeugt daraus `firmware/test/reference_vectors.h`:
Butterworth-Gütefaktoren, alle Biquad-Koeffizienten für fs = 500 und 622 Hz in
beiden Bändern, Sollfrequenzgang an sechs Stützstellen, einen goldenen Vektor
aus 64 Ein-/Ausgangswerten der Gesamtkette sowie stationäre Sollwerte für
sieben Prüffrequenzen.

`test/test_dsp.cpp` muss diese Werte reproduzieren. Die C++-Portierung ist
damit reine Übersetzungsarbeit mit objektivem Abnahmekriterium, statt einer
zweiten Implementierung, die man wieder neu glauben muss.

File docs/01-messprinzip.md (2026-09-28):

# 1. Messprinzip

## Warum kein Mikrofon

| Anforderung | Elektret / MEMS-Mikrofon | Absolut-Drucksensor (Barometer) |
|---|---|---|
| Untere Grenzfrequenz | typ. 20-100 Hz (AC-gekoppelt), 10 Hz praktisch nicht | DC bis >150 Hz, kein Hochpass |
| Max. Pegel (AOP) | 130-135 dB, danach Klirr/Clipping | ~178 dB (siehe unten) |
| Kalibrierung | Empfindlichkeit in mV/Pa, driftet, braucht Kalibrator | liefert direkt Pa, werkseitig gainkalibriert |
| Kosten | 2-15 EUR | 8-20 EUR |

Bei 1000 W Sub im Fahrzeug werden 150-160 dB erreicht. Jedes bezahlbare Mikrofon
ist dort weit im Clipping. Deshalb: **Absolut-Drucksensor als Messwandler.**

Kommerzielle Geräte dieser Klasse (z. B. Basshead Garage BHG-DB: 120-180 dB,
10-100 Hz) arbeiten nach demselben Prinzip.

## Physik

Schalldruckpegel:  `L = 20 · log10(p_rms / 20 µPa)`

| dB SPL | p_rms | p_peak |
|---|---|---|
| 120 | 20 Pa | 28 Pa |
| 140 | 200 Pa | 283 Pa |
| 150 | 632 Pa | 894 Pa |
| **155** | **1125 Pa** | **1591 Pa** (16 hPa) |
| 160 | 2000 Pa | 2828 Pa |
| 180 | 20000 Pa | 283 hPa |

Ein Barometer misst genau diese Größe direkt in Pa. Der statische Luftdruck
(~1013 hPa) wird digital weggefiltert, übrig bleibt der Wechselanteil = Schall.

**Kernvorteil:** Pa sind Pa. Es gibt keine unbekannte Mikrofonempfindlichkeit,
die kalibriert werden müsste. Die Absolutgenauigkeit hängt nur am Gain-Fehler
des Sensors (Größenordnung ±0,5 %, also ±0,05 dB) plus der Frequenzgang-
korrektur. Das ist deutlich besser als jedes selbstgebaute Mikrofonsetup.

## Sensorwahl

**Primär: Bosch BMP581**

- Bereich 30-125 kPa (300-1250 hPa)
- Auflösung 1/64 Pa (≈ 58 dB SPL rechnerische Untergrenze)
- Rauschen 0,08 Pa bei hohem Oversampling; bei OSR 1x / ~600 Hz ODR grob 1-2 Pa
  → Rauschteppich breitbandig ≈ 95-100 dB SPL, bandbegrenzt auf 10-100 Hz deutlich darunter
- ODR bis 622 Hz im Continuous Mode (SparkFun misst real ~500 Hz), FIFO 32 Werte
- I²C/SPI, 1,71-3,6 V

Aussteuerung: bei 1013 hPa Umgebungsdruck bleiben 237 hPa bis zur Obergrenze
→ **Clipping-Grenze ≈ 178 dB SPL**. Zielwert 155 dB liegt 23 dB darunter.
Nutzbare Dynamik damit rund 95 … 178 dB.

**Alternativen** (falls BMP581 nicht lieferbar):

| Sensor | ODR max | Rauschen | Bemerkung |
|---|---|---|---|
| BMP390 / BMP388 | 200 Hz | 0,02-0,9 Pa | reicht für 10-80 Hz, günstiger |
| TDK ICP-20100 | 400 Hz | 0,4 Pa | FIFO, sehr rauscharm |
| Infineon DPS310 | 128 Hz | 0,34 Pa | Nyquist nur 64 Hz, grenzwertig |

Faustregel: ODR ≥ 4 × höchste Messfrequenz. Für 10-100 Hz also ≥ 400 Hz.

## Abtastung und Aliasing

Der Sensor hat keinen analogen Anti-Aliasing-Filter. Sein ADC mittelt aber über
das Wandlungsintervall, das wirkt als sinc-Tiefpass mit Nullstelle bei fs.
Musikinhalt oberhalb 300 Hz (fs/2 bei 622 Hz) faltet sich theoretisch zurück,
liegt aber im Fahrzeug beim Basspegel typ. 30-50 dB unter dem Subbass — und der
digitale Bandpass 5-150 Hz entfernt, was nicht zurückfaltet. Für die
Zielanwendung (Bassmessung) unkritisch; im Dokument `05-kalibrierung.md` wird
das messtechnisch verifiziert.

Sinc-Korrektur, die in der Firmware auf den Betragsgang addiert wird:

| Frequenz | fs = 500 Hz | fs = 622 Hz |
|---|---|---|
| 10 Hz | +0,01 dB | +0,00 dB |
| 50 Hz | +0,14 dB | +0,09 dB |
| 100 Hz | +0,58 dB | +0,37 dB |
| 150 Hz | +1,33 dB | +0,85 dB |

Nachrechnen: `python3 tools/spl_calc.py`

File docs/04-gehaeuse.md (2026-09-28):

# 4. Gehäuse (3D-Druck)

## Material

**ASA** oder **PETG** — kein PLA. Im Fahrzeuginnenraum hinter der Scheibe sind
im Sommer 60-80 °C erreichbar, PLA verformt sich ab ~55 °C. ASA ist zusätzlich
UV-stabil.

Druckparameter: 0,2 mm Schicht, 4 Perimeter, 25 % Infill. Das Gehäuse muss
steif sein, sonst schwingt es bei 150 dB selbst mit.

## Aufbau

Zweiteilig, Front + Rückschale, verschraubt mit 8× M3 in eingelassenen
Gewindeeinsätzen (keine direkt gedruckten Gewinde — die reißen bei Vibration
aus).

```
+-----------------------------+
|  [ 2.8" TFT Ausschnitt ]    |   Front: Displayrahmen, 0,5 mm Spalt rundum
|                             |
|   o  Taster                 |
+-----------------------------+
 Rückschale:
   - Sensorkammer mit Druckport (s. u.)
   - Kabeldurchführung mit Zugentlastung
   - Saugnapf-/GoPro-Aufnahme
   - Lüftungsschlitze für den DC/DC-Wandler
```

## Der Druckport — der kritische Teil

Fehler Nummer eins bei solchen Geräten: ein dichtes Gehäuse. Das eingeschlossene
Luftvolumen bildet mit der Leckage einen Hochpass und dämpft genau die
Frequenzen weg, die gemessen werden sollen.

Regeln:

1. Die Sensorkammer ist **bewusst offen** zum Innenraum: mindestens eine
   Öffnung von 6-8 mm Durchmesser, direkt über dem Sensorport.
2. Die Kammer möglichst klein halten (< 2 cm³), Sensor direkt hinter der
   Öffnung.
3. Öffnung mit **offenporigem Schaumstoff** (5 mm, z. B. Mikrofon-Windschutz)
   abdecken: hält Staub und direkten Luftzug ab, ist bei < 200 Hz akustisch
   transparent.
4. Keine Membran, kein Gore-Tex, kein Gewebe mit Strömungswiderstand.
5. Rest der Elektronik in einer getrennten Kammer, damit Lüftungsschlitze dort
   keine Resonanzen in die Sensorkammer bringen.

## Sensorentkopplung

Die Sensorplatine auf 2 mm Moosgummi setzen und nur leicht verschrauben. Bei
150 dB wird das Gehäuse selbst zur schwingenden Masse; ein starr verschraubter
MEMS-Sensor misst diese Beschleunigung als Scheindruck mit.

## Montage im Fahrzeug

- Zwei 30-mm-Saugnäpfe an der Scheibe, oder GoPro-Mount aufs Armaturenbrett.
- **Messposition ist entscheidend und muss dokumentiert werden.** Im Fahrzeug
  entsteht ein Druckkammer-Feld mit stehenden Wellen; zwischen zwei Positionen
  liegen leicht 10 dB. Für reproduzierbare Vergleiche: feste Position
  definieren (üblich in der Szene: Windschutzscheibe mittig, oder
  Kopfstützenhöhe Fahrersitz) und immer dieselbe verwenden.
- Position im Log mit abspeichern (Freitextfeld in der Firmware).

## Dateien

Das Modell liegt fertig unter [`case/`](../case/README.md):

| Datei | Was |
|---|---|
| `case/params.scad` | **alle Maße an einer Stelle** — die einzige Datei, die anzufassen ist |
| `case/case.scad` | Rückschale und Frontblende |
| `case/sensor_chamber.scad` | Kalibrierkammer (dicht!) |
| `case/fit_test.scad` | Passungslehre, 15 min Druckzeit |
| `case/drawing.scad` | 1:1-Papiervorlage als SVG |
| `case/stl/` | fertige STLs, alle als manifold geprüft |
| `case/img/` | Vorschaubilder und Papiervorlage |

```bash
make -C case drawing   # Papiervorlage, bei 100 % ausdrucken
make -C case fit       # Passungslehre
make -C case           # alle STLs
make -C case img       # Vorschaubilder
```

**Die Maße in `params.scad` sind nicht verifiziert.** Die Angaben zum
ESP32-2432S028R widersprechen sich im Netz, und die genannte Displayfläche
passt rechnerisch nicht zu 2,8". Vor dem Druck nachmessen — die Messliste steht
in [`case/README.md`](../case/README.md).

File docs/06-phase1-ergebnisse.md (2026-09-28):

# 6. Ergebnisse Phase 1 — DSP-Modell am PC

Status: **abgeschlossen**. 99 von 99 Abnahmetests bestanden.

```bash
python3 tools/dsp_model.py         # Kennwerttabellen und Demo
python3 tools/test_dsp_model.py    # Abnahmetests, Exitcode 0 = bestanden
python3 tools/export_reference.py  # Referenzwerte fuer die C++-Portierung
```

Das Modell ist bewusst ohne numpy/scipy und strikt sample-by-sample
geschrieben. Es ist damit direkt die Vorlage für die C++-Portierung; jede
Funktion hat ein Gegenstück in `firmware/src/`.

## Festgelegte Parameter

| Parameter | Wert | Begründung |
|---|---|---|
| DC-Blocker | Hochpass 1. Ordnung, 0,5 Hz | entfernt 101 kPa Luftdruck und Wetterdrift |
| Messband A | 10–100 Hz | vergleichbar mit kommerziellen Bass-Metern |
| Messband B | 5–150 Hz | erfasst Infraschall und unteren Kickbass |
| Bandfilter | Butterworth 4. Ordnung HP + LP | −3 dB an den Bandgrenzen, 24 dB/Oktave |
| Detektor Fast | τ = 125 ms | wie bei Schallpegelmessern |
| Detektor Slow | τ = 1 s | stabiler Ablesewert |
| Einschwingsperre | 150 ms | siehe Befund 2 |
| FFT | Hann, N = 512 (LIVE) / 1024 (RTA), Hop N/4 | 1,21 / 0,61 Hz Bins bei fs = 622 Hz |

## Genauigkeit der Gesamtkette

Sinus 150,0 dB, fs = 622 Hz, Band 10–100, mit nachgebildeter Sensormittelung:

| f [Hz] | Detektorpfad | Fehler | Tonpfad (FFT) | Fehler | f0 [Hz] | Fehler |
|---|---|---|---|---|---|---|
| 10,0 | 146,97 | −3,03 | 149,97 | −0,03 | 10,003 | +0,003 |
| 20,0 | 149,94 | −0,06 | 149,98 | −0,02 | 19,996 | −0,004 |
| 31,5 | 149,97 | −0,03 | 149,98 | −0,02 | 31,493 | −0,007 |
| 50,0 | 149,97 | −0,03 | 149,98 | −0,02 | 50,010 | +0,010 |
| 63,0 | 149,91 | −0,09 | 149,98 | −0,02 | 62,990 | −0,010 |
| 80,0 | 149,45 | −0,55 | 149,98 | −0,02 | 79,990 | −0,010 |
| 100,0 | 146,97 | −3,03 | 149,98 | −0,02 | 99,991 | −0,009 |

**Zielvorgabe Phase 1 (< 0,1 dB, < 0,1 Hz) im Tonpfad über das gesamte Band
erreicht.** Der Detektorpfad liegt an den Bandgrenzen definitionsgemäß 3 dB
tiefer — das ist die Bandgrenze selbst, kein Fehler.

Linearität über 110 … 178 dB: Fehler < 0,1 dB an jedem Prüfpunkt.

## Einschwingzeiten

| | Band 10–100 | Band 5–150 |
|---|---|---|
| Bandfilter allein (99 % Amplitude) | 0,019 s | 0,018 s |
| Detektor Fast (±1 dB) | 0,198 s | 0,196 s |
| Detektor Slow (±1 dB) | 1,608 s | 1,596 s |

Das Filter selbst schwingt in 19 ms ein, weit unter der Vorgabe von 0,3 s. Die
sichtbare Trägheit kommt allein von den Detektorzeitkonstanten und ist gewollt.

## Drei Befunde, die die Firmware betreffen

### Befund 1 — FFT gehört **vor** das Bandfilter

Ursprünglich lief die FFT hinter dem Bandfilter. Ein Ton genau auf einer
Bandgrenze wurde dadurch 3 dB zu niedrig angezeigt, weil die Frequenzanzeige
die Filterflanke erbte.

Jetzt bekommt die FFT das nur DC-befreite Signal. Die Bandgrenzen wirken im
Spektralpfad rechteckig über die Bin-Auswahl. Ergebnis: Tonpfad über das ganze
Band auf ±0,03 dB genau, siehe Tabelle oben.

Zusätzlich muss die Peak-Suche **ein Bin über die Bandgrenzen hinaus** laufen.
Sonst liegt bei einem Ton exakt auf der Grenze das wahre Maximum im ersten Bin
außerhalb des Suchbereichs und die Interpolation läuft in ihre Begrenzung — im
Test ein Fehler von 0,079 Hz bei 100 Hz, jetzt 0,009 Hz.

### Befund 2 — Peak-Hold braucht eine Einschwingsperre

Ein Butterworth-Bandfilter überschwingt beim Einschwingen um gut 1 dB. Ohne
Sperre landet dieser Überschwinger als vermeintlicher Spitzenpegel im
Peak-Hold: der Test las **+4,10 dB statt +3,01 dB** über RMS, und das Gerät
hätte dauerhaft einen zu hohen Wert angezeigt.

Abhilfe: nach Start, Peak-Reset und Bandwechsel werden die Haltewerte 150 ms
lang eingefroren (`HOLD_GUARD`). Danach liest der Test 153,03 dB gegen 153,01
dB Sollspitze.

**Für die Firmware heißt das:** der Bandwechsel im Menü muss `reset_hold()`
auslösen, sonst schleppt der Peak-Wert einen Filterartefakt mit.

### Befund 3 — feste Koeffiziententabellen wären falsch

Der Sensor taktet mit einem internen RC-Oszillator, die reale Abtastrate weicht
um bis zu ±5 % vom Nennwert ab. Eine im Code fest hinterlegte
Koeffiziententabelle für „622 Hz" wäre um genau diesen Fehler daneben —
sowohl in den Filtergrenzen als auch in der Frequenzachse der FFT.

Deshalb: **die Firmware berechnet die Biquad-Koeffizienten beim Start aus der
gemessenen Abtastrate.** Das sind zwei `sin`/`cos`-Aufrufe pro Sektion, also
acht insgesamt — vernachlässigbar. `tools/export_reference.py` erzeugt keine
Firmware-Tabelle, sondern die Sollwerte für den C++-Unittest.

## Weitere abgesicherte Eigenschaften

| Prüfung | Ergebnis |
|---|---|
| Luftdruckdrift 200 Pa/s | Pegeländerung < 0,0001 dB |
| Absolutdruck 850 … 1080 hPa | Pegeländerung < 0,0001 dB |
| float32 mit vollem Luftdruckoffset | Abweichung < 0,0001 dB bei 120 dB |
| float32-Quantisierung bei 101325 Pa | 0,0078 Pa Schrittweite = 41 dB SPL, liegt 55 dB unter dem Sensorrauschen |
| Interpolationsbias | max. 0,0155 Bin = 0,0094 Hz |
| Zwei gleich starke Töne | Bandpegel +3,01 dB, wie erwartet |
| Mehrton 35 Hz / 70 Hz (−10 dB) | f0 = 34,992 Hz, Grundton 150,02 dB, Bandpegel 150,45 dB (Soll 150,41) |
| Band 10–100 gegen 130 Hz | −12,5 dB |
| BMP390 (200 Hz) mit Band 5–150 | wird mit Fehler abgelehnt — obere Grenze über Nyquist |

Die float32-Prüfung entschärft eine Sorge aus der Planung: der volle
Luftdruckoffset in float32 ist unkritisch, eine Vorab-Subtraktion im
Integerbereich ist nicht zwingend nötig. Sie bleibt trotzdem sinnvoll, weil sie
nichts kostet.

## Übergabe an Phase 3

`firmware/test/reference_vectors.h` enthält:

- Butterworth-Gütefaktoren
- alle Biquad-Koeffizienten für fs = 500 und 622 Hz, beide Bänder
- Sollfrequenzgang an sechs Stützstellen je Band
- goldener Vektor: 64 Ein-/Ausgangswerte der Gesamtkette
- stationäre Sollwerte für sieben Prüffrequenzen
- Zeitkonstanten und Sperrzeiten

Der C++-Test in Phase 3 muss diese Werte reproduzieren. Damit ist die
Portierung eine reine Übersetzungsarbeit mit objektivem Abnahmekriterium.

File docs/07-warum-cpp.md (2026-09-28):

# 7. Warum C++ auf dem Gerät und nicht durchgehend Python

Berechtigte Frage — das Python-Modell funktioniert ja. Die Antwort in einem
Satz: **Python bleibt, es wechselt nur die Rolle.** Es ist ab jetzt der
Maßstab, an dem die Gerätesoftware gemessen wird, statt selbst auf dem Gerät zu
laufen.

## Gemessen, nicht behauptet

Dieselbe Messkette, derselbe Server, identische Signale:

| | pro Sample | Echtzeitfaktor |
|---|---|---|
| Python-Modell (CPython) | 8,4 µs | 192× |
| C++-Portierung | 0,14 µs | ~11 800× |

Faktor **50–87** zugunsten von C++ (`make -C firmware bench` gegen den
Benchmark in `tools/`).

Hochgerechnet auf den ESP32 bei 240 MHz — grob geschätzt ein Faktor 50–70
langsamer als ein Kern dieses Servers:

| | Rechenlast bei 622 Hz Abtastrate |
|---|---|
| C++ auf dem ESP32 | **unter 1 %** |
| MicroPython auf dem ESP32 (Schätzung) | **grob 50 %** |

Die MicroPython-Zahl ist eine Abschätzung, keine Messung — MicroPython läuft in
diesem Container nicht. Sie ist aber auch nicht der eigentliche Grund.

## Der eigentliche Grund ist nicht Tempo, sondern Pünktlichkeit

Der FIFO des BMP581 fasst **32 Werte**. Bei 622 Hz sind das **51 Millisekunden**.
Wird er nicht rechtzeitig geleert, gehen Messwerte verloren — und zwar leise.
Das Gerät zeigt dann einen falschen Pegel an, ohne dass man es merkt.

Drei Dinge konkurrieren um diese 51 ms: das Auslesen des Sensors, der
Display-Refresh von 320×240 Pixeln und das SD-Logging.

- In C++ mit FreeRTOS wird der Sensor-Task mit hoher Priorität auf Kern 0
  festgenagelt, die Anzeige läuft auf Kern 1. Der Sensor kommt garantiert dran.
- In MicroPython teilen sich alle denselben Interpreter, und der
  Garbage Collector hält ihn unvorhersehbar für einige Millisekunden an.
  Jede Fließkommazahl wird dort auf dem Heap angelegt — bei 622 Werten pro
  Sekunde durch acht Biquads erzeugt das genau den Allokationsdruck, der den
  GC häufig laufen lässt.

Ein Messgerät, das gelegentlich still Samples verliert, ist kein Messgerät.

## Dazu kommt

- **Treiber:** Die Bosch-API für den BMP581 und `TFT_eSPI` sind C beziehungsweise
  C++. Der schnelle Display-Pfad existiert nur dort.
- **Fließkomma:** Der ESP32 hat eine Recheneinheit für einfache Genauigkeit.
  C++ nutzt sie direkt; MicroPython schiebt Objekte über den Heap.

## Was Python weiterhin macht

Das ist kein Wegwerfen, sondern der übliche Ablauf: Modell in der Sprache
bauen, in der Ausprobieren billig ist — portieren — Portierung gegen das Modell
prüfen.

| Werkzeug | Aufgabe |
|---|---|
| `tools/dsp_model.py` | Referenzmodell, 99 eigene Tests |
| `tools/export_reference.py` | erzeugt `firmware/test/reference_vectors.h` |
| `firmware/test/test_dsp/` | prüft die C++-Seite gegen genau diese Sollwerte |
| `tools/verify_log.py` (Phase 8) | wertet die Messlogs am PC aus |

Ohne diesen Umweg hätte man zwei Implementierungen, denen man beiden glauben
muss. Mit ihm hat man eine Referenz und eine Übersetzung mit hartem
Abnahmekriterium: **142 Tests**, darunter ein goldener Vektor aus 64
Ein-/Ausgangswerten, den die C++-Seite auf 0,007 Pa genau reproduziert.

Das war den Aufwand schon wert: die drei Konstruktionsfehler aus
[06-phase1-ergebnisse.md](06-phase1-ergebnisse.md) und die Nyquist-Regel unten
sind alle im Python-Modell gefunden worden, wo ein Durchlauf Sekunden dauert —
nicht auf dem Board, wo jeder Versuch Flashen und Nachmessen bedeutet.

## Neuer Befund aus der Portierung

Die Nyquist-Prüfung war zu lax. Bei 200 Hz Abtastrate liegt die obere
Bandgrenze von 100 Hz **exakt auf Nyquist**; dort entartet der Tiefpass
(w₀ = π ⇒ α = 0, das Filter verliert seine Wirkung) — und schon knapp darunter
wird die Flanke unbrauchbar verzerrt.

Jetzt gilt: **obere Bandgrenze ≤ 0,4 × Abtastrate**, also mindestens 2,5
Abtastwerte pro Periode der höchsten Messfrequenz. Ein unzulässiges Band wird
abgelehnt, statt still ein kaputtes Filter zu bauen.

Praktische Folge: ein BMP390 mit 200 Hz schafft höchstens 80 Hz obere
Bandgrenze — also weder 10–100 noch 5–150 Hz. Das bestätigt die Sensorwahl
BMP581 aus [01-messprinzip.md](01-messprinzip.md).

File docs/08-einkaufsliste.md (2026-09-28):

# 8. Einkaufsliste — AliExpress zuerst

> **Was geprüft ist und was nicht.** Die Shop-Seiten sind aus der
> Arbeitsumgebung nicht abrufbar — das Gateway lehnt `aliexpress.com`,
> `amazon.de` und `reichelt.de` mit HTTP 403 ab, das ist die Netzwerkrichtlinie
> der Umgebung. Die Artikelnummern unten stammen aus **Suchtreffern**, die
> Seiten selbst wurden **nicht geöffnet**. Preise, Lagerstand und die genaue
> Produktidentität also vor dem Kauf am Bild prüfen — besonders bei Punkt 2,
> dort gibt es eine teure Verwechslungsgefahr.
>
> Die Artikelnummer ist bei AliExpress das Dauerhafte: wenn ein Link ins Leere
> läuft, die Nummer in die Suche der App eintippen.

## Eine Bestellung, alles von AliExpress

| # | Teil | Artikelnummer | ca. |
|---|---|---|---|
| 1 | ESP32-2432S028R (CYD) | 1005004700627096 | 13 € |
| 2 | BMP581 **Breakout-Platine** | 1005005030982017 | 15 € |
| 3 | Step-Down 12 V → 5 V, **fest** | Suche, s.u. | 3 € |
| 4 | KFZ-Sicherungshalter + Sicherungen | Suche | 2 € |
| 5 | TVS-Dioden-Sortiment SMBJ/P6KE | Suche | 2 € |
| 6 | JST-XH-Set + Litze 0,75 mm² | Suche | 4 € |
| 7 | Gewindeeinsätze M3 (Set) | Suche | 4 € |
| 8 | Saugnapfhalterung 30 mm, 2× | Suche | 3 € |
| 9 | Mikrofon-Windschutz Schaumstoff | Suche | 2 € |
| 10 | Moosgummi 2 mm selbstklebend | Suche | 3 € |
| 11 | Silikonschlauch 6 mm klar + Spritze 60 ml | Suche | 4 € |
| | **Summe AliExpress** | | **~55 €** |

Dazu **Filament** (ASA oder PETG, ~25 € die Rolle) aus einem deutschen Shop —
Versandkosten und Zoll machen eine Filamentrolle aus China unattraktiv, und du
hast vermutlich ohnehin welches da.

---

## 1. ESP32-2432S028R — Rechner und Display

Mehrere bestätigte Listings, alle dasselbe Board:

| Artikelnummer | Bezeichnung im Treffer |
|---|---|
| [1005004700627096](https://de.aliexpress.com/item/1005004700627096.html) | RCmall 2.8'' ESP32-2432S028R, 240×320, ILI9341 |
| [1005004502250619](https://de.aliexpress.com/item/1005004502250619.html) | ESP32 LVGL WiFi/BT 2.8" Smart Display, im Treffer mit 9,39 US$ |
| [1005004971720824](https://de.aliexpress.com/item/1005004971720824.html) | 2.8 Inch Display Screen ESP32 LVGL WiFi BT |

**Vor dem Kaufen am Bild prüfen:** gelbe Platine, Typaufdruck
`ESP32-2432S028R`, resistiver Touch (dünner Stift liegt oft bei), microSD-Slot
an der Seite. Die Varianten `S032` und `S035` haben andere Displays und andere
Pins als in `firmware/include/config.h` hinterlegt.

Pinout zum Gegenprüfen nach Erhalt:
[Random Nerd Tutorials](https://randomnerdtutorials.com/esp32-cheap-yellow-display-cyd-pinout-esp32-2432s028r/) ·
[Mischianti](https://mischianti.org/esp32-2432s028-cheap-yellow-display-high-resolution-pinout-datasheet-schema-and-specs/)

---

## 2. BMP581 — hier ist die Falle

**Die Hälfte der „BMP581"-Angebote sind nackte Chips im LGA-10-Gehäuse:
2 × 2 × 0,5 mm, zehn Pads unter dem Bauteil.** Von Hand nicht lötbar, ohne
Platine nutzlos. Die sind billig, und genau deshalb stehen sie oben in den
Suchergebnissen.

### Das willst du — Breakout-Platinen

| Artikelnummer | Was | ca. |
|---|---|---|
| [1005005030982017](https://de.aliexpress.com/item/1005005030982017.html) | SparkFun SEN-20170 Qwiic BMP581 (Nachbau o. Reseller) | ~15 € |
| [1005011832116348](https://de.aliexpress.com/item/1005011832116348.html) | DFRobot Gravity BMP581, I2C/UART | ~14 € |
| [1005011635538614](https://de.aliexpress.com/item/1005011635538614.html) | DFRobot Fermion BMP581, I2C/SPI/I3C, 3,3 V | ~12 € |
| [1005010277584150](https://de.aliexpress.com/item/1005010277584150.html) | Adafruit-6407-Variante, STEMMA QT | ~13 € |
| [1005010701836930](https://de.aliexpress.com/item/1005010701836930.html) | „BMP581 High Precision Barometric" — Titel lässt offen, ob Platine. **Bilder prüfen.** | ~10 € |

> Die letzten drei Nummern sind aus Treffern anderer AliExpress-Länderdomains
> umgerechnet (dort `3256 8…`, hier `1005 0…` mit identischen letzten zehn
> Ziffern). Das Muster stimmt normalerweise, überprüft habe ich es nicht.

### Das willst du nicht — nackte Chips

[1005008158262909](https://de.aliexpress.com/item/1005008158262909.html)
(„BMP581 LGA-10 (2x2x0.5)") und
[1005008147941143](https://de.aliexpress.com/item/1005008147941143.html)
(„2PCS/LOT New original BMP581"). Erkennungsmerkmal im Bild: ein winziges
schwarzes Quadrat, teils auf Klebeband oder im Gurt, **ohne Platine und ohne
Stiftleiste**.

**Kaufempfehlung: zwei Stück, verschiedene Anbieter.** 28 € für zwei sind gut
angelegt — der zweite ist die Plausibilitätsprüfung aus Phase 5.3, und wenn
einer defekt oder als Chip statt Platine ankommt, steht das Projekt nicht noch
einmal vier Wochen.

**Anschluss: 3,3 V, niemals 5 V.** Laut Datenblatt maximal 3,6 V.

Wenn du nicht warten willst oder auf Nummer sicher gehen möchtest, gibt es
dasselbe in Deutschland ab Lager:
[Eckstein](https://eckstein-shop.de/SparkFun-Pressure-Sensor-BMP581-Qwiic-Compatible-with-Arduino-EN)
27,31 € · [BerryBase](https://www.berrybase.at/sparkfun-qwiic-bmp581) ~28 €.

---

## 3. Spannungsversorgung — zwei Regeln

[Suche: DC-DC 12V 24V auf 5V Step-Down](https://de.aliexpress.com/w/wholesale-dc--dc-12v-24v-to-5v-step-down-module.html)

**Regel 1: feste 5 V, kein einstellbares Modul.** Module mit Trimmpoti sind
billiger und überall zu haben — aber ein Poti in einem Fahrzeug, das von einem
1000-W-Sub durchgeschüttelt wird, kann sich verstellen. Dann liegen 12 V am
ESP32 an und das Board ist hin. Wenn es doch ein einstellbares wird: nach dem
Einstellen einen Tropfen Nagellack oder Sicherungslack aufs Poti.

**Regel 2: Eingangsbereich bis mindestens 40 V.** Load-Dump-Spitzen im Bordnetz
gehen weit über 14 V hinaus. Module mit „bis 28 V" sind zu knapp.

Zum XL4015, der oft empfohlen wird: in den Suchergebnissen finden sich
[Hinweise auf Fälschungen](https://de.aliexpress.com/w/wholesale-xl4015.html),
bei denen ein LM2596 unter dem Aufdruck sitzt und das Modul schon bei kleiner
Last heiß wird. Deshalb lieber ein fertiges KFZ-Modul mit festem 5-V-Ausgang.

**Wenn du Gewissheit willst**, ist das der eine Punkt, an dem sich eine
Reichelt-Position lohnt: **RECOM R-78B50-10**, Artikelnummer **159150**, ~7 €.
6,5–32 V Eingang, feste 5 V, 1 A, drei Pins. Damit ist die Versorgung erledigt.

**Dazu unbedingt, egal woher:**

| Teil | AliExpress-Suche |
|---|---|
| KFZ-Flachsicherungshalter + 1-A-Sicherungen | [Suche](https://de.aliexpress.com/w/wholesale-inline-blade-fuse-holder-car.html) |
| TVS-Dioden-Sortiment (SMBJ oder P6KE, 24 V) | [Suche](https://de.aliexpress.com/w/wholesale-p6ke-tvs-diode-kit.html) |
| Schottky-Dioden SS34 / 1N5822 (Verpolschutz) | [Suche](https://de.aliexpress.com/w/wholesale-ss34-schottky-diode.html) |
| Elkos 470 µF/35 V und 100 µF/16 V | [Suche](https://de.aliexpress.com/w/wholesale-electrolytic-capacitor-kit.html) |

Sicherung direkt an die Einspeisung, Schottky in Reihe, TVS parallel.
Masse sternförmig an **einem** Punkt, nicht an der Endstufenmasse — sonst
koppelt deren Ripple ein.

---

## 4. Mechanik

| Teil | Suche |
|---|---|
| Gewindeeinsätze M3 zum Einschmelzen | [Suche](https://de.aliexpress.com/w/wholesale-m3-heat-set-insert-brass.html) |
| Schrauben M3×8 Zylinderkopf | [Suche](https://de.aliexpress.com/w/wholesale-m3-socket-head-screw-kit.html) |
| Saugnapfhalterung 30 mm | [Suche](https://de.aliexpress.com/w/wholesale-suction-cup-mount-car-windshield.html) |
| Mikrofon-Windschutz Schaumstoff | [Suche](https://de.aliexpress.com/w/wholesale-microphone-foam-windscreen.html) |
| Moosgummi 2 mm selbstklebend | [Suche](https://de.aliexpress.com/w/wholesale-self-adhesive-foam-rubber-sheet-2mm.html) |

**Filament aus Deutschland**, ASA oder PETG. Kein PLA — hinter der Scheibe
werden im Sommer 60–80 °C erreicht, PLA verformt sich ab 55 °C.

---

## 5. Kalibrierhilfsmittel

| Teil | Suche | Zweck |
|---|---|---|
| Silikonschlauch 6 mm klar, 1 m | [Suche](https://de.aliexpress.com/w/wholesale-clear-silicone-tube-6mm.html) | U-Rohr-Manometer |
| Einwegspritze 60 ml | [Suche](https://de.aliexpress.com/w/wholesale-60ml-syringe.html) | DIY-Pistonphon |

Damit wird die Gain-Prüfung bis 168 dB möglich — ohne Referenzgerät.
10 cm Wassersäule sind exakt 980 Pa, also 153,8 dB. Details in
[05-kalibrierung.md](05-kalibrierung.md).

---

## Was du bewusst nicht kaufst

| Falle | Warum |
|---|---|
| **BMP581 als nackter LGA-10-Chip** | 2 × 2 mm, Pads unter dem Bauteil. Von Hand nicht lötbar. |
| **BMP280 / BME280 / BMP180** | Viel zu langsam. 100 Hz Messbereich braucht ≥ 400 Hz Abtastrate. |
| **BMP390 als Ersatz** | 200 Hz. Die Firmware lehnt damit beide Messbänder ab — obere Grenze darf höchstens 0,4 × Abtastrate sein, also 80 Hz. Nur als Zweitsensor zum Quervergleich. |
| **Einstellbares Netzteilmodul im Auto** | Trimmpoti kann sich durch Vibration verstellen, dann liegen 12 V am ESP32. |
| **Netzteilmodul mit nur 28 V Eingang** | Zu knapp für Load-Dump-Spitzen. |
| **PLA-Filament** | Verformt sich ab 55 °C. |
| **Messmikrofon jeder Art** | Clippt ab ~130 dB, unter 20 Hz taub. Begründung in [01-messprinzip.md](01-messprinzip.md). |
| **Gore-Tex oder Gewebe vor dem Druckport** | Strömungswiderstand frisst genau die tiefen Frequenzen. Nur offenporiger Schaumstoff. |
| **CYD-Varianten S032 / S035** | Andere Displays und Pins als in `config.h`. |

---

## Reihenfolge

1. AliExpress-Bestellung raus — **CYD + zwei BMP581-Breakouts** sind der
   kritische Pfad, 2–4 Wochen.
2. Filament besorgen, falls nicht vorrätig.
3. Optional Reichelt-Position R-78B50-10 (Art. 159150), wenn du beim Netzteil
   kein Risiko willst.

Warten kostet keinen Fortschritt: Phase 1 und der PC-Teil von Phase 3 sind
fertig, die 142 Tests laufen ohne Hardware.

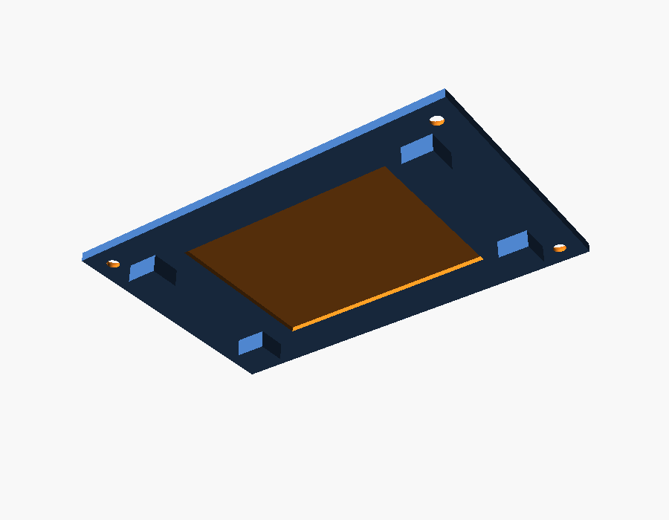
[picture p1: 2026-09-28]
case/img/bezel.png

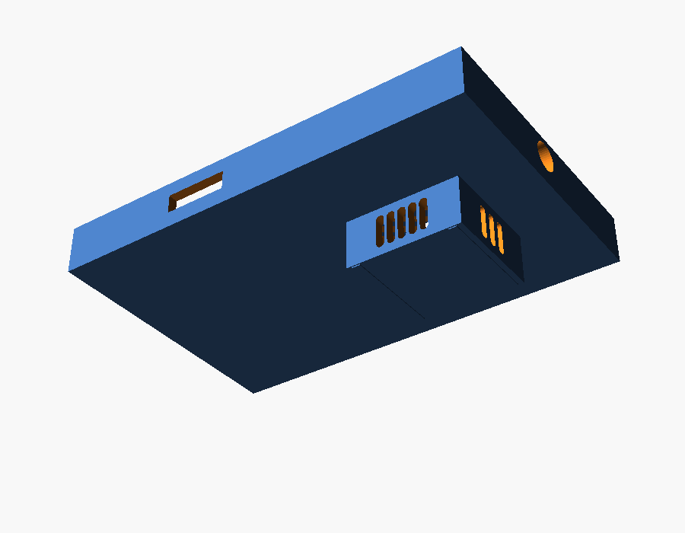
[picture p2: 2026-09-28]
case/img/back_bottom.png

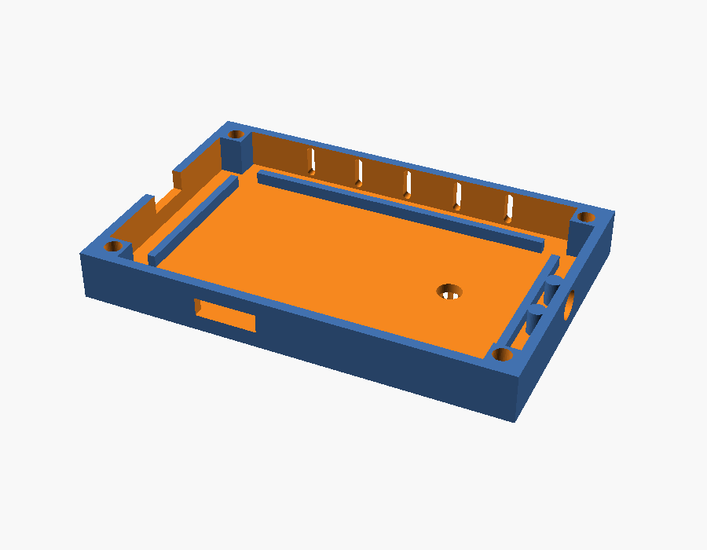
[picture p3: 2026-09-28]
case/img/back.png

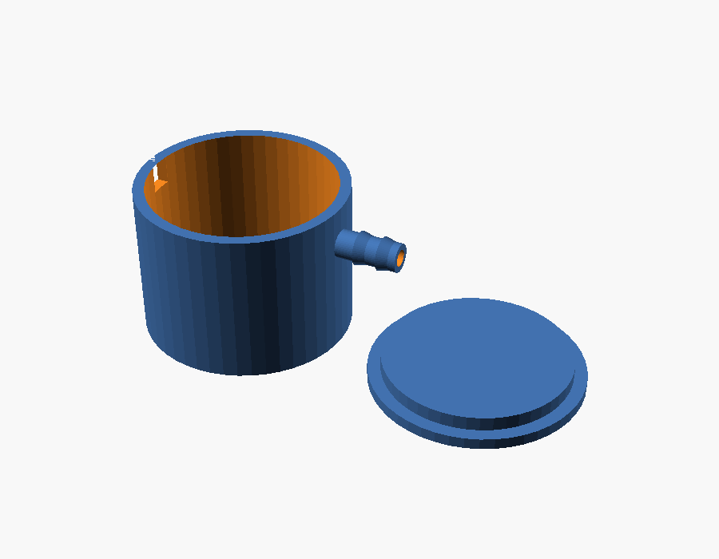
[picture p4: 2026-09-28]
case/img/cal_chamber.png

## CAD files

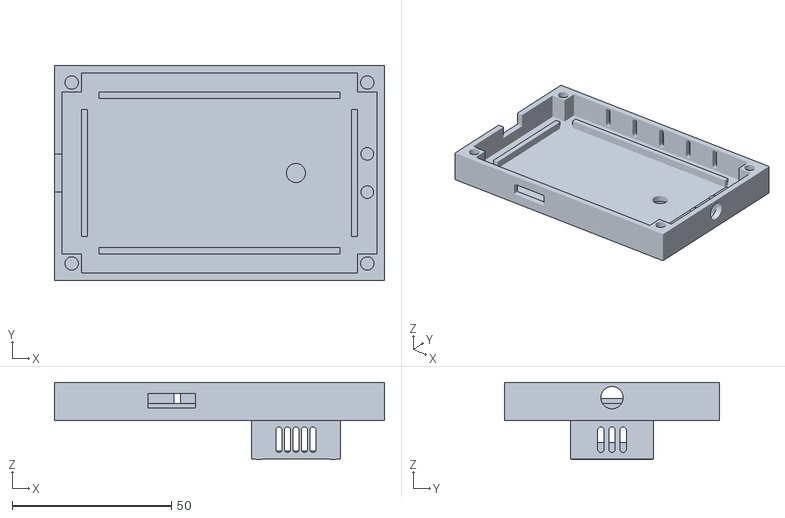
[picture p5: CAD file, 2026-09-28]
case/stl/back.stl
103.6 x 67.6 x 24.2

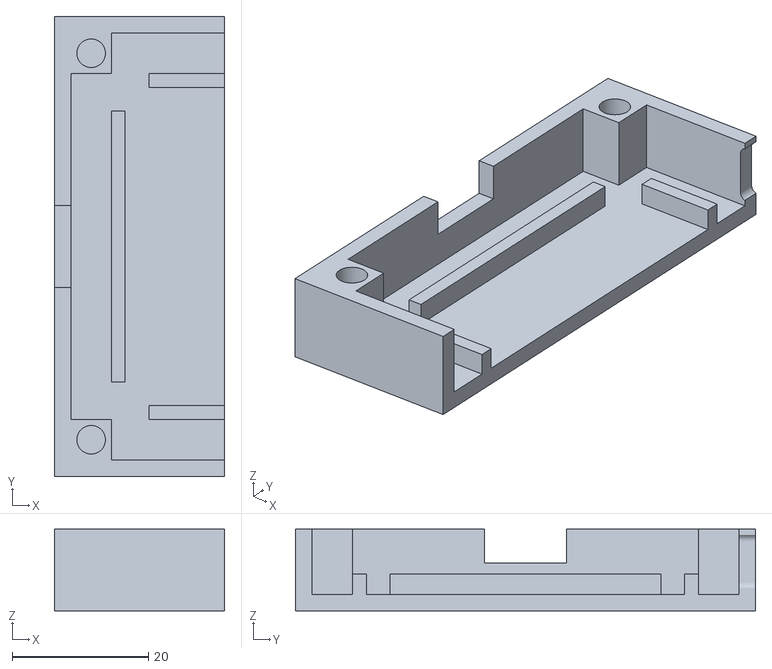
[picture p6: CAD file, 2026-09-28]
case/stl/fit_test.stl
25.0 x 67.6 x 12.0

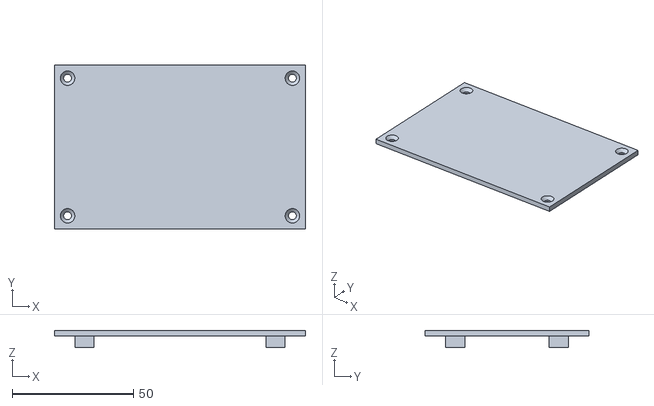
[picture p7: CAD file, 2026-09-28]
case/stl/bezel.stl
103.6 x 67.6 x 7.10

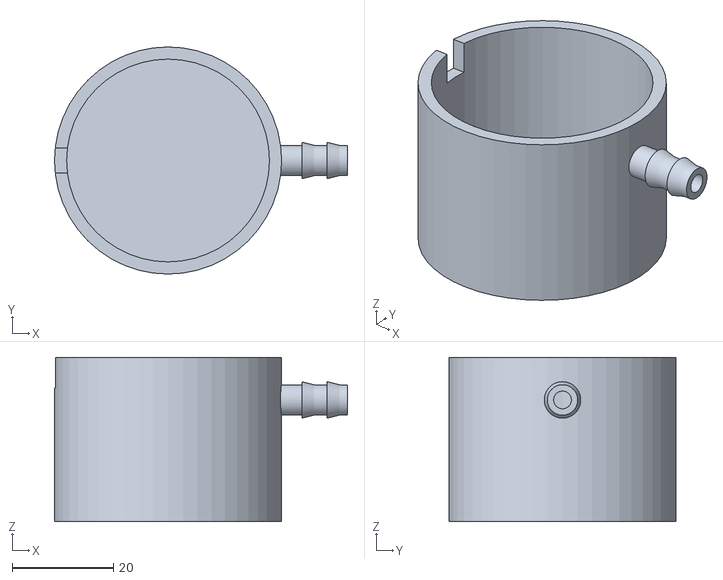
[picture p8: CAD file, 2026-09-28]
case/stl/cal_cup.stl
57.8 x 44.8 x 32.4

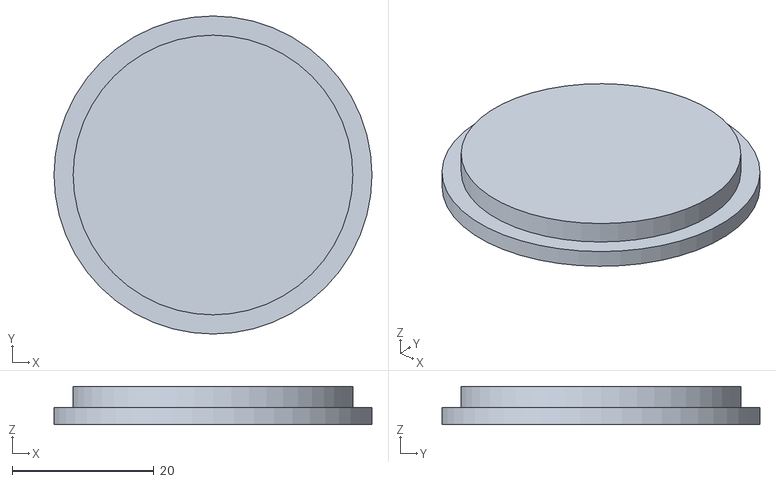
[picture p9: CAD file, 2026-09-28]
case/stl/cal_lid.stl
44.8 x 44.8 x 5.40

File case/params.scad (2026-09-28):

// Alle Masse des Projekts an einer Stelle.
//
// ============================ ACHTUNG ============================
// Die mit MESSEN markierten Werte sind NICHT verifiziert. Die im Netz
// auffindbaren Angaben zum ESP32-2432S028R widersprechen sich (78x42 mm
// gegen 102x68 mm, und die dort genannte Displayflaeche passt rechnerisch
// nicht zu 2,8" Diagonale). Sie sind hier als plausible Startwerte
// eingetragen, damit das Modell rechnet -- nicht, weil sie stimmen.
//
// Vor dem ersten grossen Druck: Board mit dem Messschieber vermessen,
// die Werte hier eintragen, dann case/fit_test.scad drucken (ca. 15 min).
// Erst wenn der passt, das Gehaeuse drucken (ca. 6 h).
// =================================================================

// ---- Leiterplatte ESP32-2432S028R ----
pcb_l          = 86.0;  // MESSEN: Laenge
pcb_w          = 50.0;  // MESSEN: Breite
pcb_t          =  1.6;  // MESSEN: Dicke
pcb_top_h      =  5.0;  // MESSEN: hoechstes Bauteil ueber der Platine (Displayrahmen)
pcb_bot_h      =  3.0;  // MESSEN: hoechstes Bauteil unter der Platine

// ---- Sichtfenster des Displays ----
// 2,8" bei 320x240 (4:3) ergibt rechnerisch 56,9 x 42,7 mm aktive Flaeche.
win_l          = 58.0;  // MESSEN: Fensterlaenge (etwas groesser als aktiv)
win_w          = 44.0;  // MESSEN: Fensterbreite
win_off_l      =  0.0;  // MESSEN: Versatz des Fensters zur Platinenmitte, Laengsrichtung
win_off_w      =  0.0;  // MESSEN: Versatz quer

// ---- Ausschnitte in den Seitenwaenden ----
usb_w          = 12.0;  // MESSEN: Breite USB-Buchse
usb_h          =  6.0;  // MESSEN: Hoehe
usb_off        =  0.0;  // MESSEN: Versatz aus der Mitte
sd_w           = 15.0;  // MESSEN: microSD-Schlitz
sd_h           =  3.0;
sd_off         = -15.0; // MESSEN: Versatz des SD-Schlitzes aus der Mitte

// ---- Gehaeuse ----
wall           =  2.4;  // Wandstaerke. 3 Perimeter bei 0,4 mm Duese + Reserve
gap            =  0.4;  // Spiel rund um die Platine
floor_t        =  2.4;
bezel_t        =  2.4;
pcb_rest       =  2.0;  // Breite der Auflageleisten unter der Platine
corner_col     =  6.0;  // Kantenlaenge der Eckpfeiler
insert_d       =  4.2;  // MESSEN: Aussendurchmesser der Gewindeeinsaetze M3
insert_h       =  5.0;  // MESSEN: Laenge
screw_d        =  3.2;  // Durchgangsloch M3
screw_head_d   =  6.0;  // Senkung
press_pad      =  8.0;  // Kantenlaenge der Andrueckpads an den Platinenecken
vent_slot_w    =  2.0;
vent_slot_n    =  5;

// ---- Sensorkammer am Geraet (belueftet!) ----
// Diese Kammer ist BEWUSST offen zur Umgebungsluft. Ein dichtes Volumen
// wuerde als Hochpass wirken und genau die tiefen Frequenzen daempfen, um
// die es hier geht. Nicht verwechseln mit der Kalibrierkammer in
// sensor_chamber.scad -- die ist dicht, weil sie das genau soll.
pod_l          = 28.0;
pod_w          = 26.0;
pod_h          = 12.0;
pod_off_l      = 24.0;  // Versatz aus der Gehaeusemitte, Laengsrichtung
sensor_pcb_l   = 25.4;  // MESSEN: Breakout-Platine, hier SparkFun Qwiic (1 x 1 Zoll)
sensor_pcb_w   = 25.4;  // MESSEN
foam_t         =  2.0;  // Moosgummi zur Entkopplung
cable_hole_d   =  6.0;

// ---- Kabeldurchfuehrung ----
grommet_d      =  7.0;
strain_post_d  =  4.0;

// ---- Kalibrierkammer (separates Teil, DICHT) ----
cal_inner_d    = 40.0;
cal_inner_h    = 30.0;
cal_wall       =  2.4;
barb_od        =  6.0;  // passend zum Silikonschlauch 6 mm innen
barb_id        =  3.5;
barb_len       = 14.0;

// ---- Druckeinstellungen als Kommentar ----
// Material ASA oder PETG, kein PLA (im Fahrzeug bis 80 C).
// 0,2 mm Schicht, 4 Perimeter, 25 % Infill, keine Stuetzen noetig
// ausser am Barb der Kalibrierkammer.

// Ueberlappung fuer Koerper, die zusammengehoeren. Flaechenbuendig
// aneinanderstossende Volumen ergeben in CGAL eine nicht-mannigfaltige
// Geometrie, die kein Slicer sauber verarbeitet.
ovl = 0.5;

$fn = 48;

// ---- Abgeleitete Groessen, nicht von Hand aendern ----
cav_l  = pcb_l + 2*gap;
cav_w  = pcb_w + 2*gap;
col_span_l = cav_l + corner_col;          // Mittenabstand der Eckpfeiler
col_span_w = cav_w + corner_col;
out_l  = col_span_l + corner_col + 2*wall;
out_w  = col_span_w + corner_col + 2*wall;
cav_h  = pcb_bot_h + pcb_t + pcb_top_h;
// Die Pads reichen von der Blendenunterseite bis knapp auf die Platine.
// 0,3 mm Luft, damit das Moosgummi den Rest uebernimmt und die Platine nicht
// verspannt wird.
press_h = pcb_top_h - 0.3;
out_h  = floor_t + cav_h;

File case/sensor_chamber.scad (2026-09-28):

// Kalibrierkammer fuer die statische Gain-Pruefung aus docs/05-kalibrierung.md.
//
// Diese Kammer ist DICHT -- im Gegensatz zur beluefteten Sensorkammer am
// Geraet. Sie soll dicht sein: nur in einem geschlossenen Volumen laesst sich
// dem Sensor ein bekannter Ueberdruck vorsetzen.
//
// part = "cup" | "lid" | "assembly"
//
// Ein Schraubglas tut es auch. Dieses Teil ist Bequemlichkeit, keine
// Notwendigkeit -- es hat nur schon die passende Schlauchtuelle dran.

include <params.scad>

part = "assembly";

od = cal_inner_d + 2*cal_wall;

// Schlauchtuelle mit zwei Widerhaken
module barb() {
    rotate([0, 90, 0]) {
        difference() {
            union() {
                cylinder(d = barb_od, h = barb_len);
                for (z = [barb_len - 4, barb_len - 9])
                    translate([0, 0, z])
                        cylinder(d1 = barb_od + 1.2, d2 = barb_od - 0.3, h = 3);
            }
            translate([0, 0, -1]) cylinder(d = barb_id, h = barb_len + 2);
        }
    }
}

module cup() {
    difference() {
        union() {
            cylinder(d = od, h = cal_inner_h + cal_wall);
            // Tuelle sitzt oben, damit kein Wasser hineinlaufen kann, falls
            // der Aufbau doch einmal kippt
            translate([od/2 - 1, 0, cal_inner_h - 6]) barb();
        }
        translate([0, 0, cal_wall])
            cylinder(d = cal_inner_d, h = cal_inner_h + 1);
        // Bohrung der Tuelle in den Innenraum
        translate([od/2 - 2, 0, cal_inner_h - 6])
            rotate([0, 90, 0])
                translate([0, 0, -8]) cylinder(d = barb_id, h = 12);
        // Kabelkerbe im Rand, wird mit Knete oder Heisskleber verschlossen
        translate([-od/2, 0, cal_inner_h + cal_wall - 3])
            cube([cal_wall*3, 5, 6], center = true);
    }
}

module lid() {
    difference() {
        union() {
            cylinder(d = od, h = cal_wall);
            // Zentrierlippe, 0,3 mm Spiel
            translate([0, 0, cal_wall])
                cylinder(d = cal_inner_d - 0.6, h = 3);
        }
        // Griffmulde
        translate([0, 0, -1]) cylinder(d = cal_inner_d - 12, h = 1.5);
    }
}

if (part == "cup")        cup();
else if (part == "lid")   lid();
else {
    cup();
    translate([od + 8, 0, 0]) lid();
}

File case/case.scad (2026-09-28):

// Gehaeuse des Bass-SPL-Meters: Rueckschale (Wanne) und Frontblende.
//
// Rendern:  make -C case
// Einzeln:  openscad -D part=\"back\" -o back.stl case/case.scad
//
// part = "back" | "bezel" | "assembly"

include <params.scad>

part = "assembly";

// ---------------------------------------------------------------- Helfer

// Eckpfeiler mit Loch fuer den Gewindeeinsatz
module corner_posts(h, hole = true) {
    for (x = [-1, 1], y = [-1, 1])
        translate([x * col_span_l/2, y * col_span_w/2, 0])
            difference() {
                translate([0, 0, h/2])
                    cube([corner_col, corner_col, h], center = true);
                if (hole)
                    translate([0, 0, h - insert_h])
                        cylinder(d = insert_d, h = insert_h + 1);
            }
}

// Reihe von Lueftungsschlitzen, laengs orientiert
module vent_slots(len, n, slot_w, depth) {
    pitch = len / (n + 1);
    for (i = [1 : n])
        translate([-len/2 + i * pitch, 0, 0])
            rotate([90, 0, 0])
                translate([0, 0, -depth/2])
                    hull() {
                        translate([0, -3, 0]) cylinder(d = slot_w, h = depth);
                        translate([0,  3, 0]) cylinder(d = slot_w, h = depth);
                    }
}

// ---------------------------------------------------------- Sensorkammer
//
// Sitzt aussen auf dem Wannenboden. Auf allen vier Seiten offen, damit der
// Sensor die Kabinenluft sieht. Genau das ist der Punkt: ein geschlossenes
// Volumen wuerde die tiefen Frequenzen wegdaempfen.
module sensor_pod() {
    difference() {
        // 0,5 mm in den Wannenboden hinein ueberlappen, nicht bloss anstossen
        translate([pod_off_l, 0, (-pod_h + ovl)/2])
            cube([pod_l, pod_w, pod_h + ovl], center = true);

        // Innenraum. Endet an der Unterseite des Wannenbodens, damit der
        // Boden seine volle Staerke behaelt und Sensorkammer und
        // Elektronikraum sauber getrennt bleiben.
        translate([pod_off_l, 0, (-pod_h + wall)/2])
            cube([pod_l - 2*wall, pod_w - 2*wall, pod_h - wall], center = true);

        // Lueftung laengs, beide Seiten
        for (y = [-1, 1])
            translate([pod_off_l, y * pod_w/2, -pod_h/2])
                vent_slots(pod_l - 2*corner_col, vent_slot_n, vent_slot_w, wall*3);

        // Lueftung quer, beide Stirnseiten
        for (x = [-1, 1])
            translate([pod_off_l + x * pod_l/2, 0, -pod_h/2])
                rotate([0, 0, 90])
                    vent_slots(pod_w - 2*corner_col, 3, vent_slot_w, wall*3);
    }
    // Auflageleisten fuer die Sensorplatine, darauf kommt das Moosgummi
    for (x = [-1, 1])
        translate([pod_off_l + x * (sensor_pcb_l/2 - 1), 0, -pod_h + wall])
            cube([2, sensor_pcb_w, wall*2 + ovl], center = true);
}

// ------------------------------------------------------------ Rueckschale

module back_shell() {
    difference() {
        union() {
            // Aussenkoerper
            translate([0, 0, out_h/2])
                cube([out_l, out_w, out_h], center = true);
            sensor_pod();
        }

        // Innenraum: bis an die Waende, nicht nur um die Platine herum.
        // Sonst blieben die Stirnseiten als massive Bloecke stehen und der
        // USB-Ausschnitt waere ein 8 mm tiefer Tunnel, in den kein Stecker
        // passt. Die Eckpfeiler stehen frei im Innenraum und dienen
        // gleichzeitig als seitliche Anschlaege fuer die Platine: ihre
        // Innenflaechen liegen genau auf dem Platinenumriss plus Spiel.
        translate([0, 0, floor_t + cav_h/2 + 1])
            cube([out_l - 2*wall, out_w - 2*wall, cav_h + 2], center = true);

        // Kabeldurchfuehrung Sensor: Wannenboden -> Kammer
        translate([pod_off_l, 0, -1])
            cylinder(d = cable_hole_d, h = floor_t + 2);

        // USB-Buchse, Schmalseite
        translate([-out_l/2, usb_off, floor_t + pcb_bot_h + pcb_t + usb_h/2])
            cube([wall*4, usb_w, usb_h], center = true);

        // microSD, Laengsseite. Kein rotate(): das vertauscht Breite und
        // Wanddurchbruch.
        translate([sd_off, -out_w/2, floor_t + pcb_bot_h + pcb_t/2])
            cube([sd_w, wall*4, sd_h + pcb_t], center = true);

        // Kabeldurchfuehrung Versorgung
        translate([out_l/2, 0, floor_t + cav_h/2])
            rotate([0, 90, 0])
                cylinder(d = grommet_d, h = wall*4, center = true);

        // Lueftung der Elektronikkammer, sonst staut sich die Waerme des
        // Spannungswandlers. Nur auf der Seite gegenueber dem
        // microSD-Ausschnitt, sonst schneiden sich die beiden.
        translate([0, out_w/2, floor_t + cav_h/2])
            vent_slots(out_l - 4*corner_col, vent_slot_n, vent_slot_w, wall*4);
    }

    // Eckpfeiler mit Einsatzloch. Starten ovl unterhalb der Bodenoberseite.
    translate([0, 0, floor_t - ovl]) corner_posts(cav_h + ovl);

    // Auflageleisten fuer die Platine. Laufen um ovl in die Eckpfeiler
    // hinein, damit sie nicht nur flaechenbuendig anstossen.
    for (x = [-1, 1])
        translate([x * (cav_l/2 - pcb_rest/2), 0, floor_t + pcb_bot_h/2])
            cube([pcb_rest, cav_w - 2*corner_col + 2*ovl, pcb_bot_h],
                 center = true);
    for (y = [-1, 1])
        translate([0, y * (cav_w/2 - pcb_rest/2), floor_t + pcb_bot_h/2])
            cube([cav_l - 2*corner_col + 2*ovl, pcb_rest, pcb_bot_h],
                 center = true);

    // Zugentlastung: zwei Pfosten im Innenraum, dazwischen ein Kabelbinder.
    // Direkt hinter der Kabeldurchfuehrung, damit Zug am Kabel nicht auf der
    // Loetstelle landet.
    // Auf col_span_l/2 gesetzt: mittig zwischen Auflageleiste und Aussenwand,
    // zu beiden je 1 mm Luft. Weiter innen lag der Zylinder exakt tangential
    // an der Leistenflaeche -- eine Beruehrung ohne Durchdringung, und genau
    // daran scheitert CGAL.
    for (y = [-1, 1])
        translate([col_span_l/2, y * 6, floor_t - ovl])
            cylinder(d = strain_post_d, h = 6 + ovl);
}

// ------------------------------------------------------------ Frontblende

module bezel() {
    difference() {
        translate([0, 0, bezel_t/2])
            cube([out_l, out_w, bezel_t], center = true);

        // Sichtfenster
        translate([win_off_l, win_off_w, -1])
            cube([win_l, win_w, bezel_t + 2], center = true);

        // Schraubenlöcher mit Senkung
        for (x = [-1, 1], y = [-1, 1])
            translate([x * col_span_l/2, y * col_span_w/2, 0]) {
                translate([0, 0, -1]) cylinder(d = screw_d, h = bezel_t + 2);
                translate([0, 0, bezel_t - 1.6])
                    cylinder(d1 = screw_d, d2 = screw_head_d, h = 1.6 + 0.01);
            }
    }
    // Andruecker: vier Pads an den Platinenecken statt einer umlaufenden
    // Rippe. Eine umlaufende Rippe wuerde auf Bauteile druecken -- wo auf
    // dieser Platine welche sitzen, weiss ich nicht. Die Ecken sind bei
    // praktisch jeder Platine frei, weil dort die Befestigungsloecher liegen.
    // Zwischen Pad und Platine kommt ein Stueck Moosgummi.
    for (x = [-1, 1], y = [-1, 1])
        translate([x * (cav_l/2 - press_pad/2), y * (cav_w/2 - press_pad/2),
                   -press_h/2])
            cube([press_pad, press_pad, press_h], center = true);
}

// ------------------------------------------------------------------ Bauen

if (part == "back")        back_shell();
else if (part == "bezel")  bezel();
else {
    back_shell();
    translate([0, 0, out_h + 12]) bezel();
}

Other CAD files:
case/drawing.scad
case/fit_test.scad

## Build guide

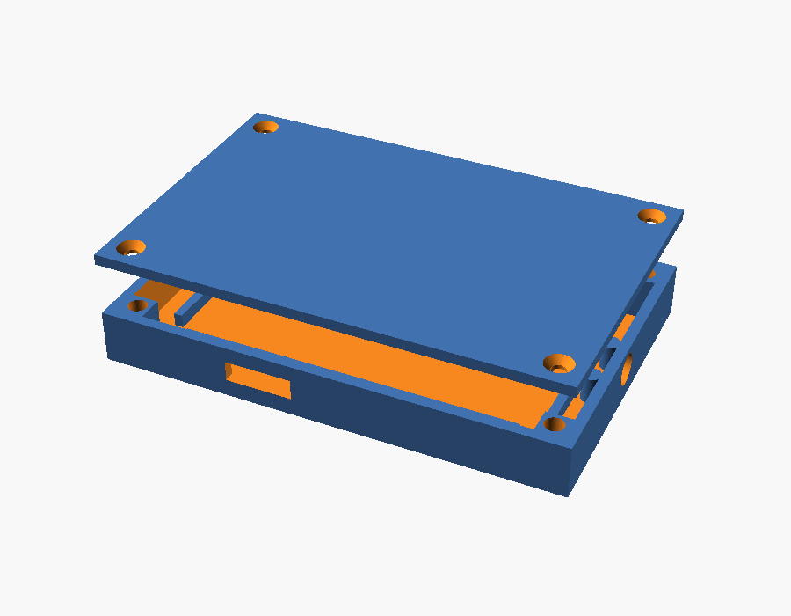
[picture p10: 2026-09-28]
case/img/assembly.png

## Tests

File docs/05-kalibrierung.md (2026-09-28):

# 5. Kalibrierung und Verifikation

Das Gerät ist durch das Messprinzip bereits absolut kalibriert (der Sensor
liefert Pa). Zu prüfen sind deshalb nur drei Dinge: **Gain**, **Frequenzgang**
und **Rauschteppich**.

## A. Gain-Prüfung mit der Wassersäule (statisch)

### Was hier eigentlich passiert

Der BMP581 misst den Druck der Luft, die an seinem Port anliegt — sonst nichts.
Um ihm einen *bekannten* Druck vorzusetzen, muss man ihn also **in ein dichtes
Volumen einsperren** und den Druck in genau diesem Volumen um einen bekannten
Betrag anheben. Ein Schlauch, der irgendwo danebenliegt, tut gar nichts.

Das Anheben übernimmt die Wassersäule. Ein U-Rohr-Manometer ist eine Waage:
steht das Wasser in den beiden Schenkeln um Δh versetzt, dann ist der Druck auf
der geschlossenen Seite genau `p_umgebung + ρ · g · Δh` — unabhängig von
Schlauchdurchmesser, Wassermenge und Volumen der Kammer. Nur die
Höhendifferenz zählt. Deshalb funktioniert die Methode mit Baumarktmaterial.

### Aufbau

```
      Spritze 60 ml
       (drückt Luft nach)
            |
            v
      +-----------+
      | T-Stück   |------ Schlauch -----> Sensorkammer (dicht, Sensor drin)
      +-----------+                        - hoch aufhaengen! -
            |
         Schlauch
            |
            v
      +--------------------+
      |   U-Rohr, Wasser   |   offenes Ende zur Raumluft
      |   Delta h ablesen  |
      +--------------------+
```

**Sensorkammer:** ein kleines Schraubglas oder ein Stück 20-mm-Rohr mit zwei
Kappen. Zwei Durchführungen: eine Schlauchtülle für den Schlauch, eine Bohrung
für das Sensorkabel. Beide mit Heißkleber oder Epoxid abdichten. Das Volumen
ist egal — nur die Dichtheit zählt.

**Die Kammer gehört nach oben, das U-Rohr nach unten**, mit reichlich Schlauch
dazwischen. Wasser im Sensor ist das Ende des Sensors.

### Ablauf

1. Alles drucklos. Am Gerät den **Rohdruck** ablesen → `p0`.
   Das ist der Wert `rawPressurePa` aus dem Report; er liegt vor dem
   DC-Blocker, weil genau der sonst die zu messende Größe entfernen würde.
2. Spritze langsam eindrücken, bis das Wasser um Δh versetzt steht.
3. **30 s warten.** Komprimierte Luft erwärmt sich; der Druck sinkt danach
   noch etwas, bis die Temperatur wieder stimmt. Der BMP581 liefert die
   Temperatur mit, daran lässt sich das Einschwingen beobachten.
4. Δh mit dem Stahllineal ablesen, gleichzeitig den Rohdruck → `p1`.
5. Prüfen: `p1 − p0` muss `ρ · g · Δh` entsprechen.

Das für mehrere Höhen wiederholen — 10, 20, 50 cm. Ein einzelner Punkt zeigt
nur einen Offset; erst die Reihe zeigt, dass der Gain über den Bereich stimmt.

### Sollwerte (Wasser bei 20 °C, ρ = 998,2 kg/m³, g = 9,80665 m/s²)

| Δh | Überdruck | als Effektivwert | Ablesefehler bei ±1 mm |
|---|---|---|---|
| 5 cm | 489 Pa | 147,8 dB | ±2,0 % |
| 10 cm | 979 Pa | 153,8 dB | ±1,0 % |
| 20 cm | 1958 Pa | 159,8 dB | ±0,5 % |
| **50 cm** | **4896 Pa** | **167,8 dB** | **±0,2 %** |

**Nimm die 50 cm als Hauptmesspunkt.** Bei 10 cm ist dein Lineal der
begrenzende Faktor, nicht der Sensor. Bei 50 cm liegt der Ablesefehler mit
0,2 % gleichauf mit der Temperaturabhängigkeit des Wassers (15 → 25 °C sind
ebenfalls 0,2 %) — zusammen etwa 0,3 %. Genauer wird diese Methode nicht, und
genauer muss sie auch nicht sein.

Die dB-Spalte ist reine Umrechnung zur Einordnung: 4896 Pa sind der
Effektivdruck, den ein 167,8-dB-Ton hätte. Es ist ein statischer Druck, kein
Schall — aber in derselben Größenordnung wie das, was du später misst.

**Prüfkriterium: Abweichung < 1 %.** Damit ist die Pa-Skala des Sensors über
den gesamten Messbereich bestätigt, mit Hausmitteln und ohne Referenzgerät.
Das kann kein Mikrofonaufbau.

### Lecks erkennen

Ein Leck verrät sich von selbst: Rohdruck und Wasserstand sinken gemeinsam und
stetig. Bleiben beide über eine Minute stabil, ist der Aufbau dicht. Sinkt nur
der Druck, ohne dass sich das Wasser bewegt — dann misst du falsch, prüf die
Verbindung zur Kammer.

### Sofort-Check ohne jeden Aufbau

Bevor du irgendetwas baust: Der Luftdruck fällt mit der Höhe um **rund 12 Pa
pro Meter**. Trag das Gerät drei Stockwerke hoch, das sind etwa 10 m, und der
Rohdruck muss um ~120 Pa fallen. Kostet nichts, dauert zwei Minuten und deckt
grobe Fehler sofort auf: falscher Sensor, falsche Einheit, kaputte Skalierung.

### Was diese Prüfung nicht abdeckt

Sie prüft den **Gain bei 0 Hz**. Sie sagt nichts über den Frequenzgang — dafür
ist Abschnitt B da. Und sie prüft nicht die Signalkette dahinter (Bandfilter,
FFT, Detektoren); die ist bereits durch die 151 Tests in
`firmware/test/test_dsp/` abgedeckt und braucht keine Hardware.

## B. Frequenzgang mit DIY-Pistonphon (dynamisch)

Bekanntes Volumen V, Lautsprecher verschiebt ΔV:
`Δp = γ · P₀ · ΔV / V` (γ = 1,4 adiabat)

Aufbau: Marmeladenglas o. ä. mit bekanntem Volumen, Deckel mit kleinem
Lautsprecher dicht eingeklebt, Sensorport dicht eingeführt. Speaker mit Sinus
10-150 Hz ansteuern.

Der absolute Wert ist damit nur grob bestimmbar (ΔV ist schwer zu messen),
**der relative Frequenzgang aber sehr gut** — und genau den braucht man, um die
Sinc-Korrektur und eventuelle Kammerresonanzen zu bestätigen. Erwartung: flach
±0,5 dB von 10 bis 100 Hz.

Fallback ohne Pistonphon: Zwei Sensoren unterschiedlichen Typs (BMP581 +
BMP390) parallel im Fahrzeug messen lassen. Systematische Abweichungen zeigen
sich als Differenz über der Frequenz.

## C. Rauschteppich

Gerät in einem ruhigen Raum betreiben, 60 s aufzeichnen, SPL im Band 10-100 Hz
auswerten. Erwartung: 85-100 dB, abhängig vom Oversampling. Das ist der
untere Rand des Messbereichs — für Bassmessungen ab 120 dB völlig ausreichend,
aber im Datenblatt des eigenen Geräts ehrlich anzugeben.

## D. Vergleich im Fahrzeug

Gegen ein vorhandenes Gerät (TermLAB, BHG-DB, oder das Gerät eines Kollegen auf
einem Treffen) an identischer Position gegenmessen. Erwartete Abweichung bei
sauberer Umsetzung: wenige dB — Restdifferenzen kommen fast immer von
unterschiedlicher Sensorposition, nicht vom Gerät.

## E. Was das Gerät NICHT kann

Ehrlichkeitsabschnitt für die Doku:

- Kein geeichtes Messgerät, keine Klasse-1/2-Zertifizierung nach IEC 61672.
- Keine offiziellen Wettbewerbsergebnisse — dafür gelten dort vorgeschriebene
  Geräte und Mikrofonpositionen.
- Oberhalb ~150 Hz nicht ausgelegt (Anti-Aliasing, Sinc-Korrektur).
- Absolutwerte hängen stark von der Messposition im Fahrzeug ab.

## Dokumentation der Kalibrierung

Ergebnisse in `docs/kalibrierprotokoll.md` festhalten: Datum, Seriennummer des
Sensors, gemessene fs, Wassersäulen-Abweichung in %, Rauschteppich, ggf.
eingetragener Korrekturoffset in dB.

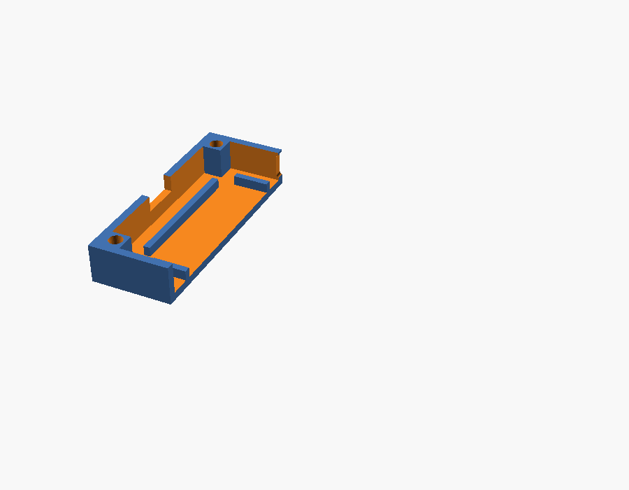
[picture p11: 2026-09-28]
case/img/fit_test.png

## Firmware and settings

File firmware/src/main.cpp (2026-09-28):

// Zielsystem: ESP32-2432S028R ("Cheap Yellow Display").
//
// Laeuft auch OHNE angeschlossenen Sensor. Wird beim Start keiner gefunden,
// schaltet das Geraet in den Demobetrieb: ein synthetisches Signal laeuft
// durch dieselbe Messkette wie spaeter der echte Schall. Damit lassen sich
// Display, Rechenkette und Anzeige auf echter Hardware pruefen, bevor der
// BMP581 eintrifft.
//
// Offen (Phase 2): der eigentliche Sensortreiber. Die Erkennung unten liest
// nur die Chip-ID -- dafuer braucht es keine Herstellerbibliothek.

#include <Arduino.h>
#include <TFT_eSPI.h>
#include <Wire.h>

#include "../include/config.h"
#include "meter.h"

namespace {

TFT_eSPI tft;
vu::Meter g_meter;

float g_fs = cfg::kFsNominal;
int g_backlight = cfg::kBacklightDefault;  // Prozent
int g_sensorAddr = -1;   // -1 = kein Sensor gefunden, Demobetrieb
uint32_t g_samples = 0;  // verarbeitete Messwerte, fuer die Statuszeile

// ------------------------------------------------- Hintergrundbeleuchtung

// Helligkeit in Prozent. Ueber PWM, damit sie sich regeln laesst.
//
// Sich auf TFT_eSPI zu verlassen reicht nicht: die Bibliothek schaltet den Pin
// hoechstens einmal beim init() ein. Alles, was danach den Pin anfasst --
// etwa ein Wire.begin() auf demselben GPIO -- macht das wieder zunichte.
// Deshalb hier explizit und nach allen anderen Initialisierungen.
void setBacklight(int percent) {
    if (percent < 0) percent = 0;
    if (percent > 100) percent = 100;
    g_backlight = percent;
    const uint32_t duty = (percent * ((1u << cfg::kBacklightBits) - 1)) / 100;

#if defined(ESP_ARDUINO_VERSION_MAJOR) && ESP_ARDUINO_VERSION_MAJOR >= 3
    // Arduino-Core 3.x hat die LEDC-Schnittstelle vereinfacht.
    ledcAttach(cfg::kBacklightPin, cfg::kBacklightPwmHz, cfg::kBacklightBits);
    ledcWrite(cfg::kBacklightPin, duty);
#else
    ledcSetup(cfg::kBacklightPwmCh, cfg::kBacklightPwmHz, cfg::kBacklightBits);
    ledcAttachPin(cfg::kBacklightPin, cfg::kBacklightPwmCh);
    ledcWrite(cfg::kBacklightPwmCh, duty);
#endif
}

// ------------------------------------------------------------------ Sensor

// Liest ein Register ueber I2C. Gibt false zurueck, wenn niemand antwortet.
bool readReg(int addr, uint8_t reg, uint8_t* value) {
    Wire.beginTransmission(addr);
    Wire.write(reg);
    if (Wire.endTransmission(false) != 0) return false;
    if (Wire.requestFrom(addr, 1) != 1) return false;
    *value = Wire.read();
    return true;
}

// Sucht den BMP581 auf beiden moeglichen Adressen.
int findSensor() {
    for (int i = 0; i < 2; ++i) {
        uint8_t id = 0;
        if (readReg(cfg::kBmp581Addr[i], cfg::kBmp581RegChipId, &id) &&
            id == cfg::kBmp581ChipId) {
            return cfg::kBmp581Addr[i];
        }
    }
    return -1;
}

// ----------------------------------------------------------- Demosignal

// Sinus mit linearem Frequenzsweep, auf Umgebungsdruck aufgesetzt. Die
// Momentanphase wird fortlaufend integriert, sonst springt das Signal bei
// jedem Frequenzwechsel und die FFT sieht einen Knacks statt eines Tons.
float demoSample(float dt) {
    static float phase = 0.0f;
    static float t = 0.0f;
    t += dt;
    if (t > cfg::kDemoSweepS) t -= cfg::kDemoSweepS;

    const float k = t / cfg::kDemoSweepS;
    const float f = cfg::kDemoFreqLo + k * (cfg::kDemoFreqHi - cfg::kDemoFreqLo);
    phase += 2.0f * PI * f * dt;
    if (phase > 2.0f * PI) phase -= 2.0f * PI;

    const float amp = vu::paFromSpl(cfg::kDemoSpl) * sqrtf(2.0f);
    return cfg::kDemoAmbientPa + amp * sinf(phase);
}

// -------------------------------------------------------------- Anzeige

constexpr uint16_t kBg = TFT_BLACK;
constexpr uint16_t kFg = TFT_WHITE;
constexpr uint16_t kDim = 0x7BEF;  // mittleres Grau
constexpr uint16_t kAccent = TFT_CYAN;
constexpr uint16_t kWarn = TFT_ORANGE;

constexpr int kSpecY = 150;   // Oberkante des Spektrums
constexpr int kSpecH = 78;
constexpr int kSpecX = 8;
constexpr int kSpecW = 304;

void drawStatic() {
    tft.fillScreen(kBg);
    tft.setTextDatum(TL_DATUM);
    tft.setTextColor(kDim, kBg);
    tft.drawString("dB SPL", 232, 64, 2);
    tft.drawFastHLine(0, 140, 320, kDim);
    tft.drawFastHLine(kSpecX, kSpecY + kSpecH, kSpecW, kDim);
}

void drawSpectrum(const vu::Meter& m) {
    if (!m.spectrumReady()) return;
    const vu::Spectrum& sp = m.spectrum();
    const float* mags = m.magnitudes();
    const vu::BandLimits& bl = vu::bandLimits(m.band());

    // Ein Balken je Pixelspalte, logarithmisch ueber der Frequenz -- so
    // bekommt der Bereich unter 30 Hz genug Platz.
    const float logLo = log10f(bl.lo), logHi = log10f(bl.hi);
    for (int px = 0; px < kSpecW; ++px) {
        const float f = powf(10.0f, logLo + (logHi - logLo) * px / kSpecW);
        int k = static_cast<int>(f / sp.binHz() + 0.5f);
        if (k < 1) k = 1;
        if (k > sp.magCount() - 1) k = sp.magCount() - 1;

        // Bin-Betrag in einen Pegel umrechnen und auf 100..170 dB abbilden
        const float pa = 2.0f * mags[k] / (sp.size() * 0.5f) / sqrtf(2.0f);
        const float db = vu::splFromPa(pa);
        int h = static_cast<int>((db - 100.0f) / 70.0f * kSpecH);
        if (h < 0) h = 0;
        if (h > kSpecH) h = kSpecH;

        const int x = kSpecX + px;
        tft.drawFastVLine(x, kSpecY, kSpecH - h, kBg);
        if (h > 0) tft.drawFastVLine(x, kSpecY + kSpecH - h, h, kAccent);
    }
}

void drawReadings(const vu::Report& r) {
    char buf[48];

    // Grosser Pegelwert
    tft.setTextDatum(TR_DATUM);
    tft.setTextColor(kFg, kBg);
    snprintf(buf, sizeof(buf), "%5.1f", r.splSlow);
    tft.drawString(buf, 228, 30, 7);

    // Dominante Frequenz
    tft.setTextDatum(TL_DATUM);
    tft.setTextColor(kAccent, kBg);
    snprintf(buf, sizeof(buf), "%6.2f Hz", r.f0);
    tft.drawString(buf, 8, 106, 4);

    // Spitzenwerte
    tft.setTextDatum(TR_DATUM);
    tft.setTextColor(kDim, kBg);
    snprintf(buf, sizeof(buf), "max %5.1f  peak %5.1f", r.splMaxRms, r.splPeak);
    tft.drawString(buf, 312, 112, 2);

    // Statuszeile
    tft.setTextDatum(TL_DATUM);
    tft.setTextColor(r.pressurePlausible ? kDim : kWarn, kBg);
    snprintf(buf, sizeof(buf), "%s Hz  %.0f/s  %s  %d%%", r.band, g_fs,
             g_sensorAddr < 0 ? "DEMO" : "BMP581", g_backlight);
    tft.drawString(buf, 8, 224, 2);
}

// ---------------------------------------------------------------- Tasks

// Hohe Prioritaet, eigener Kern. Beim echten Sensor fasst der FIFO nur
// 32 Werte, das sind 51 ms bei 622 Hz -- laenger darf dieser Task nicht
// blockiert werden, sonst gehen Messwerte verloren.
void sensorTask(void*) {
    const TickType_t period = pdMS_TO_TICKS(cfg::kFifoReadIntervalMs);
    TickType_t last = xTaskGetTickCount();
    uint32_t prevUs = micros();

    for (;;) {
        if (g_sensorAddr >= 0) {
            // TODO(Phase 2): FIFO-Burst lesen, Overrun-Flag auswerten, jeden
            // Wert durch g_meter.process(pa) schicken.
        } else {
            // Demobetrieb: so viele Werte erzeugen, wie in der verstrichenen
            // Zeit angefallen waeren. An der echten Uhr ausgerichtet, damit
            // die angezeigte Frequenz stimmt.
            const uint32_t now = micros();
            const uint32_t dtUs = now - prevUs;
            prevUs = now;
            int n = static_cast<int>(dtUs * 1e-6f * g_fs + 0.5f);
            if (n > 256) n = 256;  // nach einer Blockade nicht aufholen wollen
            const float dt = 1.0f / g_fs;
            for (int i = 0; i < n; ++i) g_meter.process(demoSample(dt));
            g_samples += n;
        }
        vTaskDelayUntil(&last, period);
    }
}

void uiTask(void*) {
    const TickType_t period = pdMS_TO_TICKS(1000 / cfg::kDisplayFps);
    TickType_t last = xTaskGetTickCount();
    for (;;) {
        const vu::Report r = g_meter.report();
        drawReadings(r);
        drawSpectrum(g_meter);
        vTaskDelayUntil(&last, period);
    }
}

void splash(const char* line1, const char* line2, uint16_t color) {
    tft.fillScreen(kBg);
    tft.setTextDatum(MC_DATUM);
    tft.setTextColor(color, kBg);
    tft.drawString(line1, 160, 100, 4);
    if (line2) {
        tft.setTextColor(kDim, kBg);
        tft.drawString(line2, 160, 140, 2);
    }
}

}  // namespace

void setup() {
    Serial.begin(115200);

    tft.init();
    tft.setRotation(1);  // Querformat, 320 x 240

    // I2C vor dem Einschalten der Beleuchtung starten. Sollte je wieder ein
    // Pin doppelt belegt werden, faellt es dann wenigstens nicht erst nach
    // dem Einschalten auf -- die static_asserts in config.h verhindern es
    // ohnehin schon zur Uebersetzungszeit.
    Wire.begin(cfg::kI2cSda, cfg::kI2cScl, cfg::kI2cHz);
    setBacklight(cfg::kBacklightDefault);

    splash("Bass-SPL-Meter", "Sensor wird gesucht", TFT_WHITE);
    g_sensorAddr = findSensor();

    if (g_sensorAddr >= 0) {
        Serial.printf("BMP581 auf 0x%02X gefunden\n", g_sensorAddr);
        // TODO(Phase 2): Continuous Mode, Oversampling 1x, IIR auf Bypass,
        // FIFO einschalten, dann die Abtastrate ueber 30 s messen.
        splash("BMP581 gefunden", "Treiber folgt in Phase 2", TFT_GREEN);
    } else {
        Serial.println("Kein Sensor gefunden, Demobetrieb");
        splash("Kein Sensor", "Demobetrieb mit Testsignal", TFT_ORANGE);
    }
    delay(1500);

    if (!g_meter.init(g_fs, vu::Band::k10to100, cfg::kFftLive)) {
        splash("FEHLER", "Abtastrate zu niedrig fuer das Band", TFT_RED);
        Serial.println("Meter::init fehlgeschlagen");
        return;
    }

    drawStatic();
    xTaskCreatePinnedToCore(sensorTask, "sensor", 4096, nullptr, 10, nullptr, 0);
    xTaskCreatePinnedToCore(uiTask, "ui", 8192, nullptr, 3, nullptr, 1);
}

void loop() {
    // Alle 5 s ein Lebenszeichen auf die serielle Schnittstelle. Nuetzlich,
    // wenn das Display noch nicht richtig konfiguriert ist.
    static uint32_t last = 0;
    if (millis() - last > 5000) {
        last = millis();
        const vu::Report r = g_meter.report();
        Serial.printf("%s  %6.1f dB  f0 %6.2f Hz  peak %6.1f  roh %.0f Pa  n=%lu\n",
                      g_sensorAddr < 0 ? "DEMO" : "BMP", r.splSlow, r.f0,
                      r.splPeak, r.rawPressurePa,
                      static_cast<unsigned long>(g_samples));
    }
    vTaskDelay(pdMS_TO_TICKS(200));
}

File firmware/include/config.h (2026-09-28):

// Zentrale Konfiguration: Pins, Vorgaben, Grenzwerte.
#pragma once

namespace cfg {

// ---- Pins (ESP32-2432S028R) ----------------------------------------------
// Vor dem Loeten gegen die eigene Boardrevision pruefen -- von den CYD-Boards
// gibt es mehrere Varianten. Frei sind ueblicherweise GPIO 21, 22 und 35.
// GPIO 21 ist auf dem CYD die Hintergrundbeleuchtung und darf hier NICHT
// stehen, auch wenn 21/22 die Arduino-Standardpins fuer I2C sind: Wire.begin()
// konfiguriert den Pin um und schaltet damit das Licht aus. Frei und auf den
// Steckern herausgefuehrt sind 22, 27 und 35 (nur Eingang).
constexpr int kI2cSda = 27;
constexpr int kI2cScl = 22;
constexpr int kI2cHz = 400000;
constexpr int kSensorIntPin = 35;  // optional, nur Eingang
constexpr int kButtonPin = 0;      // Boot-Taster, alternativ Touch

// ---- Hintergrundbeleuchtung ----
// Aktiv HIGH. Wird per PWM angesteuert, damit sich die Helligkeit regeln
// laesst -- im dunklen Fahrzeug blendet volle Helligkeit, tagsueber reicht sie
// gerade so.
constexpr int kBacklightPin = 21;
constexpr int kBacklightPwmCh = 7;      // LEDC-Kanal
constexpr int kBacklightPwmHz = 5000;
constexpr int kBacklightBits = 8;       // 0 .. 255
constexpr int kBacklightDefault = 80;   // Prozent

// Sicherung gegen genau den Fehler, der das Licht einmal ausgeschaltet hat:
// liegt ein I2C-Pin auf dem Backlight-Pin, schaltet Wire.begin() ihn um.
static_assert(kI2cSda != kBacklightPin,
              "I2C-SDA liegt auf dem Backlight-Pin: Wire.begin() wuerde die "
              "Hintergrundbeleuchtung ausschalten");
static_assert(kI2cScl != kBacklightPin,
              "I2C-SCL liegt auf dem Backlight-Pin: Wire.begin() wuerde die "
              "Hintergrundbeleuchtung ausschalten");

// ---- Sensor: Erkennung ohne Herstellerbibliothek ----
// Der BMP581 meldet sich auf 0x47 (SDO high) oder 0x46 (SDO low) und liefert
// in Register 0x01 die Chip-ID 0x50. Das reicht, um festzustellen, ob ein
// Sensor angeschlossen ist -- ohne eine Bibliothek einzubinden, die erst in
// Phase 2 gebraucht wird.
constexpr int kBmp581Addr[2] = {0x47, 0x46};
constexpr int kBmp581RegChipId = 0x01;
constexpr int kBmp581ChipId = 0x50;

// ---- Demobetrieb ohne Sensor ----
// Wird kein Sensor gefunden, speist das Geraet ein synthetisches Signal durch
// dieselbe Messkette und zeigt es an. Damit laesst sich das Display und die
// gesamte Rechenkette auf echter Hardware pruefen, bevor der Sensor da ist --
// und man sieht sofort, ob die Anzeige plausible Werte liefert.
constexpr float kDemoSpl = 150.0f;   // Pegel des Testsignals
constexpr float kDemoFreqLo = 20.0f; // Sweep von ...
constexpr float kDemoFreqHi = 80.0f; // ... bis
constexpr float kDemoSweepS = 12.0f; // Dauer eines Durchlaufs
constexpr float kDemoAmbientPa = 101325.0f;

// ---- Sensor ---------------------------------------------------------------
constexpr float kFsNominal = 622.0f;   // Continuous Mode, OSR 1x
constexpr float kFsCalibSeconds = 30.0f;  // Dauer der Abtastraten-Kalibrierung
constexpr int kFifoReadIntervalMs = 40;   // FIFO fasst 32 Werte = 51 ms
// Plausibilitaetsgrenzen fuer den Rohdruck. Ausserhalb -> "OVER" anzeigen.
constexpr float kPressureMinPa = 35000.0f;
constexpr float kPressureMaxPa = 120000.0f;

// ---- Messung --------------------------------------------------------------
constexpr int kFftLive = 512;   // 1,21 Hz Bins bei 622 Hz, Update 4,9/s
constexpr int kFftRta = 1024;   // 0,61 Hz Bins, Update 2,4/s
constexpr float kClipWarnSpl = 175.0f;

// ---- Anzeige --------------------------------------------------------------
constexpr int kDisplayFps = 5;
constexpr int kLongPressMs = 600;  // Peak-Reset

}  // namespace cfg

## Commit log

2026-09-14 Plan und Abarbeitungsliste für Bass-SPL-Meter (10-100 Hz)
    Konzept für ein Selbstbau-Messgerät für Subbass-Schalldruckpegel in
    Fahrzeugen: Absolut-Drucksensor (BMP581) statt Mikrofon, ESP32 mit
    2,8"-TFT, Messbereich ca. 95-178 dB SPL, 10-100 Hz.
    - docs/01-messprinzip.md: Sensorwahl, Physik, Aliasing, Sinc-Korrektur
    - docs/02-hardware.md: Stückliste (55-85 EUR), Pinbelegung, Bordnetzschutz
    - docs/03-firmware.md: Signalkette, FFT-Parameter, Betriebsmodi
    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
2026-09-14 Phase 1: DSP-Referenzmodell mit 99 Abnahmetests
    Komplette Messkette als Referenzmodell in reiner Standardbibliothek,
    sample-by-sample geschrieben und damit direkt nach C++ portierbar.
    Genauigkeit im Tonpfad: +/-0,03 dB und +/-0,01 Hz ueber das gesamte
    Messband, Linearitaet 110-178 dB besser als 0,1 dB. Bandfilter schwingt
    in 19 ms ein.
    Umgesetzte Entscheidungen aus der Rueckfrage:
    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
2026-09-14 Phase 3: C++-Portierung der Messkette, 142 Tests gegen das Modell
    Hardwareunabhaengiger Teil von Phase 3 vorgezogen. Der DSP-Kern ist frei
    von Arduino- und ESP-IDF-Abhaengigkeiten, laeuft deshalb im PC-Test und
    wird dort gegen die Referenzwerte aus dem Python-Modell geprueft.
    Abnahme: 142 von 142 Tests gruen. Der goldene Vektor aus 64
    Ein-/Ausgangswerten wird auf 0,007 Pa genau reproduziert, alle
    Biquad-Koeffizienten auf 1e-6, die stationaeren Tonpegel auf 0,05 dB.
    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
2026-09-14 Einkaufsliste mit Bezugsquellen und Artikelnummern
    docs/08-einkaufsliste.md: Bezugsquellen fuer AliExpress, Amazon, Reichelt,
    Pollin und die deutschen Maker-Shops, aufgeteilt in Kernteile,
    Bordnetzschutz, Mechanik und Kalibrierhilfsmittel. Dazu zwei
    Bestellwege (schnell/guenstig) und eine Liste der Teile, die man
    bewusst NICHT kaufen sollte.
    Kalkulation korrigiert: der BMP581 kostet in Deutschland 27-29 EUR statt
    der geschaetzten 8-19 EUR; ueber AliExpress (DFRobot Fermion) rund
    12-15 EUR. Gesamtsumme damit 55 EUR (AliExpress-Weg) bis 95 EUR
    (deutscher Weg) statt 55-85 EUR.
    Ausserdem den DC/DC-Wandler auf RECOM R-78B50-10 geaendert (6,5-32 V
    Eingang, Reichelt Art. 159150) statt eines MP158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
2026-09-14 Verbliebene Kostenangaben an die korrigierte Kalkulation angeglichen
    Claude-Session: https://claude.ai/code/session_01RpHumgVZ9vb7skVuUD87PH
2026-09-15 Einkaufsliste auf AliExpress umgestellt, mit konkreten Artikelnummern
    Die Liste ist jetzt als eine einzige AliExpress-Bestellung aufgebaut
    (~55 EUR), mit bestaetigten Artikelnummern fuer das CYD-Board und
    fuenf BMP581-Breakouts.
    Wichtigste Ergaenzung: die Haelfte der AliExpress-Angebote unter dem
    Suchwort BMP581 sind nackte LGA-10-Chips (2 x 2 x 0,5 mm, Pads unter
    dem Bauteil), nicht lotbar von Hand. Zwei solche Fallen-Listings sind
    namentlich aufgefuehrt, damit sie sich am Bild erkennen lassen.
    Zwei Regeln fuer das Netzteil ergaenzt: fester 5-V-Ausgang statt
    Trimmpoti (das kann sich im Fahrzeug durch Vibration verstellen, dann
    liegen 12 V am ESP32) und Eingangsbereich bis mindestens 40 V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
2026-09-15 Absolutdruck-Ausgang ergaenzt, Wassersaeulen-Kalibrierung neu beschrieben
    Die Beschreibung der statischen Gain-Pruefung in docs/05 war nicht
    durchfuehrbar ("ein Schenkel an den Sensorport"). Sie verschwieg, dass
    der Sensor in ein dichtes Volumen eingesperrt werden muss, damit ein
    bekannter Druck ueberhaupt an ihm anliegt. Abschnitt A jetzt mit
    Aufbauskizze, Ablauf, Leckerkennung und Fehlerrechnung.
    Dabei fiel eine echte Luecke auf: die Firmware hatte keinen Ausgang fuer
    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
2026-09-15 Parametrisches Gehaeusemodell in OpenSCAD
    Rueckschale mit belueftetem Sensor-Pod, Frontblende mit Andrueckpads,
    dichte Kalibrierkammer, Passungslehre und 1:1-Papiervorlage. Alle fuenf
    STLs von CGAL als manifold bestaetigt.
    Ablauf so angelegt, dass Fehldrucke vermieden werden: Papiervorlage
    (ein Blatt) -> Masse eintragen -> Passungslehre (15 min) -> Gehaeuse
    (6 h). Die Passungslehre schneidet ein 25 mm langes Stueck aus der
    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
    [back.stl, bezel.stl, cal_cup.stl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]
2026-09-28 CI: Modell, Messkette, ESP32-Firmware und Gehaeuse bauen
    Die ESP32-Firmware liess sich bisher nirgends uebersetzen -- meine
    Arbeitsumgebung sperrt die PlatformIO-Registry (connect_rejected fuer
    api.registry.platformio.org). main.cpp war damit ungepruefter Text.
    GitHub Actions schliesst genau diese Luecke und legt die Binaerdatei als
    Artefakt ab, damit sich das Board ohne lokale Toolchain flashen laesst.
    Vier Jobs:
    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
2026-09-28 Firmware laeuft ohne Sensor: Demobetrieb mit Anzeige
    Das Board ist da, der Sensor noch nicht. Findet die Firmware beim Start
    keinen BMP581, speist sie einen synthetischen Sweep von 20 auf 80 Hz bei
    150 dB durch dieselbe Messkette wie spaeter den echten Schall und zeigt
    das Ergebnis an. Damit laesst sich mit dem Board allein pruefen, ob
    Display, Rotation und Rechenkette stimmen: die Anzeige muss konstant
    150,0 dB zeigen und die Frequenz in 12 s durchlaufen.
    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
2026-09-28 CI: Rechte des Workflows auf Lesezugriff beschraenken
    Die Jobs bauen und testen nur, keiner schreibt ins Repository.
    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
2026-09-28 CI: PlatformIO-Testanbindung pruefen, ueberholte Laeufe abbrechen
    test/test_custom_runner.py war ausgeliefert, aber von nichts ausgefuehrt.
    Er uebersetzt die Ausgabe der eigenen Testsuite in PlatformIO-Testfaelle,
    damit 'pio test -e native' dieselben Ergebnisse zeigt wie das Makefile.
    Lokal liess sich das nicht pruefen, weil die PlatformIO-Registry hier
    gesperrt ist -- also genau der Zustand, gegen den CI da ist. Neuer Job
    pio-native fuehrt ihn aus.
    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
2026-09-28 CI: auch auf Arbeitszweigen bauen
    Der Workflow lief bisher nur auf main und bei offenem Pull Request. PR #1
    war beim Hinzufuegen des Workflows schon gemerged, also griff kein
    Trigger und es entstand nie ein Lauf.
    Fuer dieses Projekt ist das die falsche Voreinstellung: die
    ESP32-Firmware laesst sich nirgends sonst uebersetzen, das Ergebnis
    braucht man also waehrend der Arbeit am Zweig und nicht erst beim
    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
2026-09-28 Gemessene Speicherbelegung eintragen, TOUCH_CS-Warnung erklaeren
    Der erste CI-Lauf ist gruen, alle fuenf Jobs. main.cpp wurde damit zum
    ersten Mal gegen die echte Arduino-API uebersetzt: RAM 15,0 % statisch,
    Flash 25,4 %, Bauzeit 48 s. Die Zahlen ersetzen die Schaetzungen in
    docs/03-firmware.md.
    TFT_eSPI warnt beim Bauen, dass TOUCH_CS nicht definiert ist. Das ist
    hier richtig so und jetzt im platformio.ini begruendet: der
    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
2026-09-28 Hintergrundbeleuchtung: Pinkonflikt beheben, Helligkeit regelbar
    Auf dem Board war das Bild korrekt, die Beleuchtung aber aus. Ursache:
    I2C lag auf GPIO 21 -- und das ist auf dem CYD der Backlight-Pin.
    tft.init() schaltete das Licht ein, das darauf folgende Wire.begin(21, 22)
    konfigurierte den Pin als SDA um und wieder aus.
    Die Wahl 21/22 stammte von mir: es sind die Arduino-Standardpins fuer
    I2C, und ich hatte eine fruehere, richtige Belegung 27/22 damit
    korrigiert. Zurueck auf 27/22; frei sind auf dem CYD 22, 27 und 35.
    Damit das nicht wiederkommt, pruefen zwei static_assert in config.h zur
    Uebersetzungszeit, dass kein I2C-Pin auf dem Backlight-Pin liegt. Die
    Sperre ist gegengeprueft: mi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
    [config.h, main.cpp]
